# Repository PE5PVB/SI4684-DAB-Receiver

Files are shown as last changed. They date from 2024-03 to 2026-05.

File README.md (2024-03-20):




# Note:
The version in the repository is an ongoing development. It could and will contain bugs. To make sure you use the latest fully tested firmware, check the releases!

# SI4684 DAB receiver
Advanced DAB Tuner software for Skyworks SI4684 tuner with ESP32 board and a color LCD\
More information: https://www.pe5pvb.nl/

# Building instructions
On Youtube I published a video how to build your own radio.

In English:
https://www.youtube.com/watch?v=C_xd0h_HTuU

In Dutch:
https://www.youtube.com/watch?v=wV3G2J327qg

# Libraries
These are the libraries used for this project:
- https://github.com/Bodmer/TFT_eSPI
- https://github.com/Bodmer/JPEGDecoder
- https://github.com/bitbank2/PNGdec

Use these settings in the TFT_eSPI library:
```
#define ILI9341_DRIVER
#define TFT_CS          5
#define TFT_DC          4
#define TFT_RST         17
#define SPI_FREQUENCY   50000000
#define SMOOTH_FONT
```
# Buttons
A brief instruction for the buttons:
- Top encoder: Choose frequency or memory channel
- Bottom encoder: Choose service or set headphones volume
- Top button: Short press: Service information, Long press: Stand-by mode.
- Middle button: Short press: Set mode, Long press: Open menu.
- Lower button: Toggle Slideshow view.
  
## Contributing
I'm open for a new ideas in our project. Feel free to share your thoughts in [Discussions](https://github.com/PE5PVB/SI4684-DAB-Receiver/discussions).\
You can also contribute your own code using [Pull Requests](https://github.com/PE5PVB/SI4684-DAB-Receiver/pulls). We will review it and merge into main branch.

You are using my software and you found a difficulty? Please create new [issue](https://github.com/PE5PVB/SI4684-DAB-Receiver/issues) and describe your problem.

I also would like to invite you to join our Discord community where we share our ideas and help each other with some issues.\
[Join the TEF6686 Discord community!](https://discord.gg/ZAVNdS74mC)  

Special thanks to all [contributors](https://github.com/PE5PVB/TEF-Nextion-Multiband/graphs/contributors). You are awesome! ❤️
## License
This program is free software; you can redistribute it and/or modify it under the terms of the GNU General Public License as published by the Free Software Foundation; either version 3 of the License, or (at your option) any later version.

This program is distributed in the hope that it will be useful, but WITHOUT ANY WARRANTY; without even the implied warranty of MERCHANTABILITY or FITNESS FOR A PARTICULAR PURPOSE. See the GNU General Public License for more details. 

## If you like this software


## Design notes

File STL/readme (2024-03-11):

Many thanks to Eric-Jan de Boer for this 3d case design!

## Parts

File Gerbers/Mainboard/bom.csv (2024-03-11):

Designator | Footprint | Quantity | Value | LCSC Part #
C1, C14, C15, C17, C26, C35, C4, C41 | 0603 | 8 | 1uF
C12, C23, C29, C38 | 0603 | 4 | 8p2
C18, C19, C21, C6 | 0603 | 4 | 100n
C25, C30, C40, C7 | 0603 | 4 | 2n2
C3 | 0603 | 1 | 33p
C34, C39 | 0603 | 2 | 270p
C5 | 0603 | 1 | 2p7
D1 | SOT-23 | 1 | BAV99
L1 | 0603 | 1 | 18nH
L2 | 0603 | 1 | BEAD
L3 | 0603 | 1 | 120nH
L4 | 0603 | 1 | 22nH
R1 | 0603 | 1 | 4k7
R10, R11 | 0603 | 2 | 220
R2, R3, R4, R5, R8, R9 | 0603 | 6 | 100
R25, R26 | 0603 | 2 | 10k
U1 | SOT-23-5 | 1 | MIC5504-1.8YM5
U3 | QFN-48-1EP_7x7mm_P0.5mm_EP5.3x5.3mm | 1 | SI4684-A10-GM
U5 | QFN-20-1EP_4x4mm_P0.5mm_EP2.7x2.7mm | 1 | TPA6130A2RTJTG4 | TPA6130A2RTJTG4
X1 | Crystal_SMD_3225-4Pin_3.2x2.5mm | 1 | 19.2MHz

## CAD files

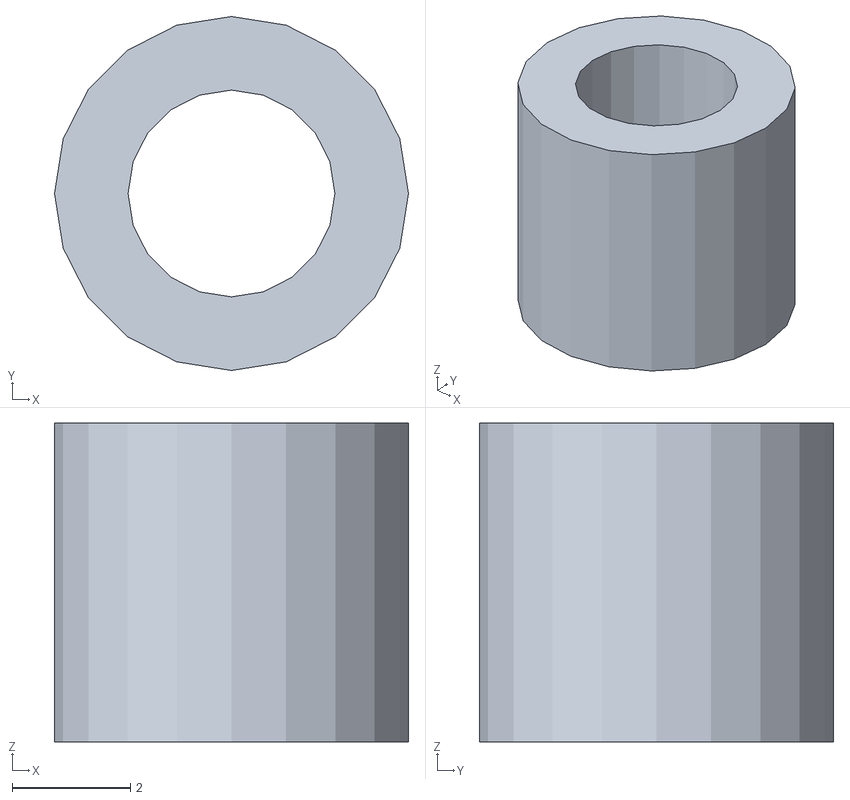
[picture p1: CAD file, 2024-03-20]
STL/bus.stl
6.00 x 6.00 x 5.40

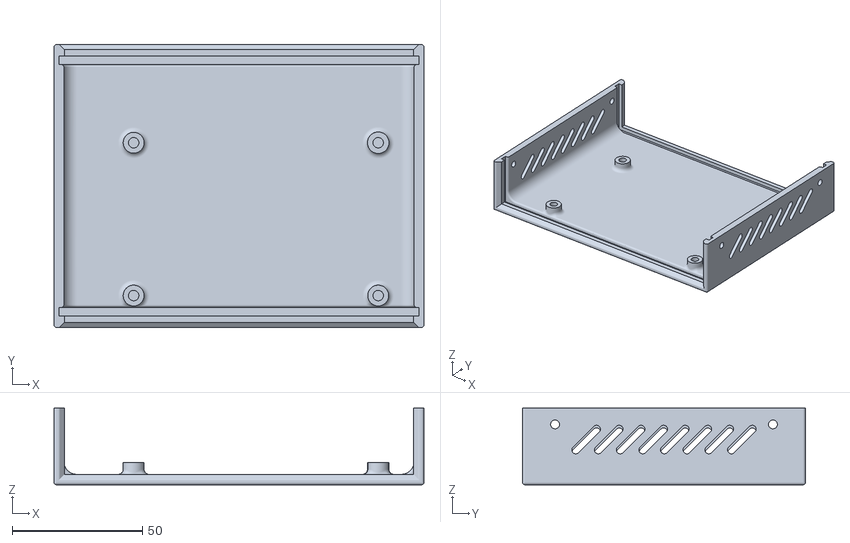
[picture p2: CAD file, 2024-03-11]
STL/bottom.stl
141.9 x 108.5 x 29.4

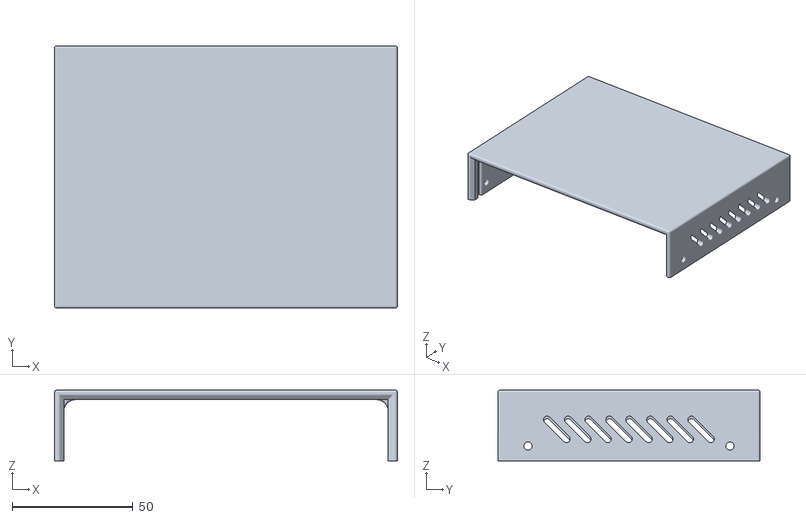
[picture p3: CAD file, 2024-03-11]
STL/top.stl
141.9 x 108.5 x 29.4

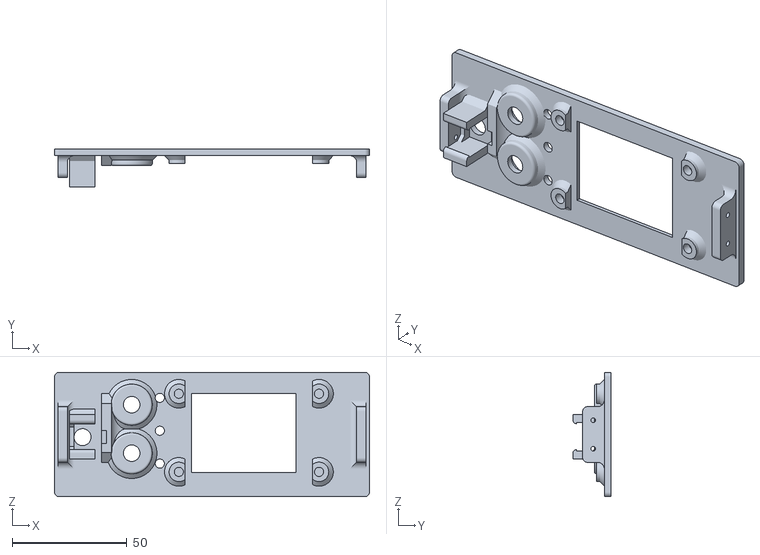
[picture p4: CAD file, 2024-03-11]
STL/front.stl
137.5 x 16.8 x 54.3

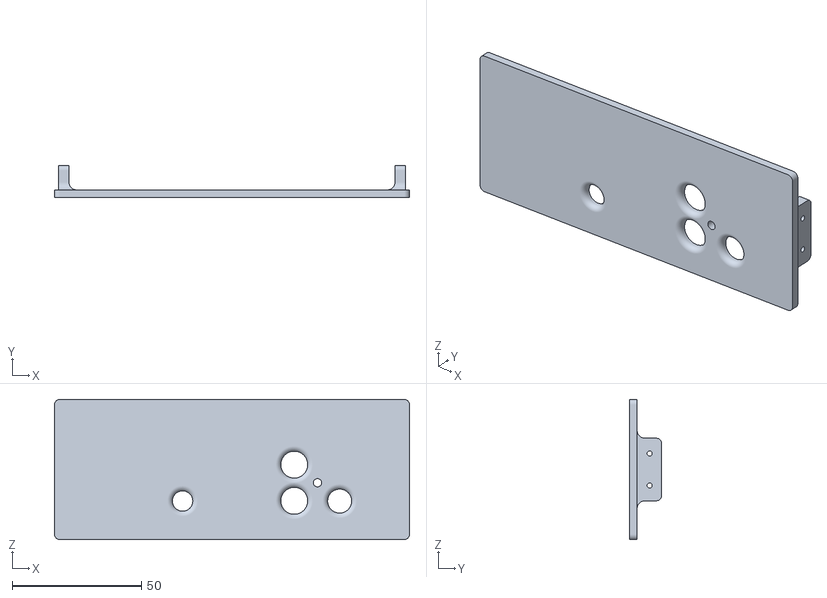
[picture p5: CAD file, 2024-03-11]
STL/back.stl
137.5 x 12.5 x 54.3

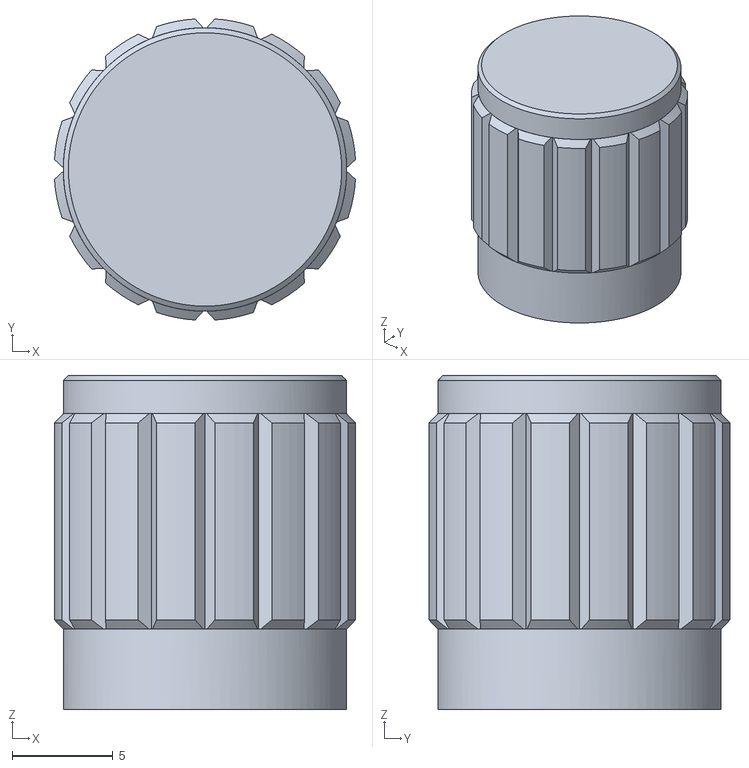
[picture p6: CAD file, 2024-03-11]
STL/rotary knob.stl
15.0 x 15.0 x 16.6

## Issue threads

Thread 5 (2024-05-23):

Petite Modification dand si4684.cpp et .h

GOUNOT, 2024-05-23:
Bonjour ,

Voici les fichier si4684.cpp et . h
Ajout radio.vol(x); Volume de sortie
SID et EID recalculés

Pascal
[si4684h.txt](https://github.com/PE5PVB/SI4684-DAB-Receiver/files/15418648/si4684h.txt)
[si4684cpp.txt](https://github.com/PE5PVB/SI4684-DAB-Receiver/files/15418651/si4684cpp.txt)

PE5PVB, 2024-05-23:
Hi Pascal,

Thanks. I applied your changes to the repository.

Maybe you can help me out with translation of the language.h to French?

BTW. Do you have EPG data on your DAB bouquets? We don’t, and I like to parse now/next EPG for the current service and show it in a separate window when long press the slideshow button.

Sjef

Van: GOUNOT ***@***.***>
Verzonden: donderdag 23 mei 2024 16:57
Aan: PE5PVB/SI4684-DAB-Receiver ***@***.***>
CC: Subscribed ***@***.***>
Onderwerp: [PE5PVB/SI4684-DAB-Receiver] Petite Modification dand si4684.cpp et .h (Issue #5)

Bonjour ,

Voici les fichier si4684.cpp et . h
Ajout radio.vol(x); Volume de sortie
SID et EID recalculés

Pascal
si4684h.txt <https://github.com/PE5PVB/SI4684-DAB-Receiver/files/15418648/si4684h.txt>
si4684cpp.txt <https://github.com/PE5PVB/SI4684-DAB-Receiver/files/15418651/si4684cpp.txt>

—
Reply to this email directly, view it on GitHub <https://github.com/PE5PVB/SI4684-DAB-Receiver/issues/5> , or unsubscribe <https://github.com/notifications/unsubscribe-auth/ASI5LNMQ2QZ265M7S2TS5BLZDX7URAVCNFSM6AAAAABIF2XZHKVHI2DSMVQWIX3LMV43ASLTON2WKOZSGMYTGMJUGUYTKMI> .
You are receiving this because you are subscribed to this thread.  <https://github.com/notifications/beacon/ASI5LNOVHNT73I6TKVCY7Z3ZDX7URA5CNFSM6AAAAABIF2XZHKWGG33NNVSW45C7OR4XAZNFJFZXG5LFVJRW63LNMVXHIX3JMTHITX6LH4.gif> Message ID: ***@***.*** ***@***.***> >

PE5PVB, 2024-06-05:
I tried your modification but it mess up German.
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

Closed 2024-06-05.

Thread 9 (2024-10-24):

Kicad files

alfrede, 2024-10-24:
Hi, thanks for this outstanding Projekt. Will you release the kicad Projekt files?

PE5PVB, 2025-01-22:
Why do you want the source files?

nona00, 2025-01-26:
Great project! With the KiCad files, one could design simplified PCBs, for example, a breakout board for ESP32. Smaller than DAB Shield.

PE5PVB, 2025-01-26:
Just added the Kicad files. Please respect the license.

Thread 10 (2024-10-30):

Utilisation VScode et PlatformIO and  Partition of ESP32 memory

joellecam, 2024-10-30:
Hi,

First, You have made a very good project. I am retired from an Electronics job of 42 years.  For my hobby I continue some projects. for software I prefer VScode with platformio vs Arduino Ide.   I have made my dabshield pcb (photo) and I try to adapt your software.

I try to use VScode with PlatformIO to works and run the SI4684-DAB. the compilation generate a too big exe file. I change the partition files to have no OTA, that double the application place.  see partition file --> File ESP32_4MB_NON_OTA.csv hereunder.
Then the compilation is done without error and I have free space memory.  the dowloading  was aso ok.

when rebboting  I have an error at the begining when fuction  "LittleFS.begin()" run. see hereunder. Is the error due to the partition scheme?

Platformio.ini  ( with LittleFS  build filesystem and partitions scheme)
```
; https://docs.platformio.org/page/projectconf.html
[env:esp32dev]
platform = espressif32
board = esp32dev
monitor_speed = 115200
board_build.partitions = ESP32_4MB_NON_OTA.csv
board_build.filesystem = littlefs
framework = arduino
```

File ESP32_4MB_NON_OTA.csv
```
# Name,   Type, SubType, Offset,  Size, Flags
nvs,      data, nvs,     0x9000,  0x5000,
otadata,  data, ota,     0xe000,  0x2000,
app0,     app,  ota_0,   0x10000, 0x280000,
spiffs,   data, spiffs,  0x290000,0x150000,
coredump, data, coredump,0x3F0000,0x10000,
```

debug monitor listing

```
--------------------
Rebooting...
LittleFS.begin()

assert failed: lfs_fs_grow_ lfs.c:5165 (block_count >= lfs->block_count)

Backtrace: 0x40083cc5:0x3ffb1e50 0x4008bd81:0x3ffb1e70 0x400916dd:0x3ffb1e90 0x4010546c:0x3ffb1fc0 0x40100f76:0x3ffb2020 0x40101082:0x3ffb2070 0x400de4fd:0x3ffb21e0 0x400dab56:0x3ffb2210 0x400ee1ca:0x3ffb2290

ELF file SHA256: 87c1a721b5c09ac3
Rebooting...
-------------------
```
Thanks very much for your help.

Joël  , leeve in Normandie, France.
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

Closed 2024-10-30.

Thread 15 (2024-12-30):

to much memory

McKaiver, 2024-12-30:
when i compile the scetch with all libraries, i get the warning:
Sketch is using 3180057 Bytes (242%)

i have this controller:
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

what's wrong here?

PE5PVB, 2024-12-30:
Select "High APP" for compiling and use ESP32 boardmanager v2.x

McKaiver, 2024-12-30:
I'm using Arduino IDE 2.2.1

Closed 2025-02-24.

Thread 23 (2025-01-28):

Reduced Circuit for I2S Output

harryberlin, 2025-01-28:
Hello,

inspired by your project i designed a PCB for ESP32 with PCM5102 and SI468**8**, instead of SI468**4**

[AVR-IBus.dab.schematic.pdf](https://github.com/user-attachments/files/18578988/AVR-IBus.dab.schematic.pdf)

<Image width=300 src=https://github.com/user-attachments/assets/85ba1679-1bd4-4248-8c1a-f421ad6ef8ed>

(BTW. Reset and Boot Mode has an error)

For first Test i have stripped and added some prints to your code.
After begin the IC returns "SI0" ChipID and "0.0.0" as Firmware Version
that's the result of setup method:

```
void setup(void) {
  WRITE_PERI_REG(RTC_CNTL_BROWN_OUT_REG, 0);

  setupmode = true;

  Serial.begin(115200);
  Serial.println("SETUP STARTING ....");
  pinMode(RESET_PIN, OUTPUT);
  digitalWrite(RESET_PIN, LOW);
  delay(50);
  digitalWrite(RESET_PIN, HIGH);
  delay(50);

  EEPROM.begin(EE_TOTAL_CNT);
  if (EEPROM.readByte(EE_BYTE_CHECKBYTE) != EE_CHECKBYTE_VALUE) DefaultSettings();
  ContrastSet = EEPROM.readByte(EE_BYTE_CONTRASTSET);
  language = EEPROM.readByte(EE_BYTE_LANGUAGE);
  displayflip = EEPROM.readByte(EE_BYTE_DISPLAYFLIP);
  rotarymode = EEPROM.readByte(EE_BYTE_ROTARYMODE);
  tunemode = EEPROM.readByte(EE_BYTE_TUNEMODE);
  unit = EEPROM.readByte(EE_BYTE_UNIT);
  dabfreq = EEPROM.readByte(EE_BYTE_DABFREQ);
  volume = EEPROM.readByte(EE_BYTE_VOLUME);
  memorypos = EEPROM.readByte(EE_BYTE_MEMORYPOS);
  autoslideshow = EEPROM.readByte(EE_BYTE_AUTOSLIDESHOW);
  tot = EEPROM.readByte(EE_BYTE_TOT);
  CurrentTheme = EEPROM.readByte(EE_BYTE_THEME);
  //radio.BufferSlideShow = EEPROM.readByte(EE_BYTE_BUFFERSLIDESHOW);

  for (int i = 0; i < EE_PRESETS_CNT; i++) {
    memory[i].Channel = EEPROM.readByte(i + EE_PRESETS_FREQ_START);
    EEPROM.get((i * 8) + EE_PRESETS_SERVICEID_START, memory[i].ServiceID);
    for (int y = 0; y < 16; y++) {
      memory[i].Label[y] = EEPROM.readByte((i * 17) + y + EE_PRESETS_NAME_START);
    }
    memory[i].Label[16] = '\0';
  }
  Serial.println("EEPROM DONE");

  delay(50);

  Serial.println("Starting DAB.....");
  if (radio.begin(15)) {
    Serial.println("Starting DAB OK");
  } else {
    for (;;);
  }

  delay(1500);
  Serial.println("Starting DAB DONE");
  Serial.println("TUNE ...");
  if (tunemode == TUNE_MEM && !IsStationEmpty()) {
    DoMemoryPosTune();
  } else {
    if (tunemode == TUNE_MEM) tunemode = TUNE_MAN;
    radio.setFreq(dabfreq);
    EEPROM.get(EE_UINT32_SERVICEID, _serviceID);
    for (int i = 0; i < 16; i++) {
      _serviceName[i] = EEPROM.readByte(i + EE_CHAR17_SERVICENAME);
    }
  }
  if (_serviceID != 0 ) trysetservice = true;

  Serial.println("TUNE DONE");
  setupmode = false;
  tottimer = millis();

  Serial.println("SETUP DONE");
  Serial.println(String(radio.getChipID()));
  Serial.println(String(radio.getFirmwareVersion()));
}
```

that's my log
```
19:48:30.479> ets Jul 29 2019 12:21:46
19:48:30.479>
19:48:30.479> rst:0x1 (POWERON_RESET),boot:0x13 (SPI_FAST_FLASH_BOOT)
19:48:30.479> configsip: 0, SPIWP:0xee
19:48:30.479> clk_drv:0x00,q_drv:0x00,d_drv:0x00,cs0_drv:0x00,hd_drv:0x00,wp_drv:0x00
19:48:30.479> mode:DIO, clock div:1
19:48:30.479> load:0x3fff0030,len:1344
19:48:30.479> load:0x40078000,len:13964
19:48:30.479> load:0x40080400,len:3600
19:48:30.479> entry 0x400805f0
19:48:30.779> SETUP STARTING ....
19:48:30.917> EEPROM DONE
19:48:30.979> Starting DAB.....
19:48:30.979> SPIbuffer[1]:0x80
19:48:31.032> DAB WRITE FIRMWARE
19:48:32.532> DAB WRITE FREQLIST
19:48:32.601> Starting DAB OK
19:48:34.101> Starting DAB DONE
19:48:54.144> SETUP DONE
19:48:54.144> SI0
19:48:54.144> 0.0.0
```

Are there some possible tests to find the problem?
Do you think your firmware is not for the IC?
I hope you could give some support, to get my device working?

PE5PVB, 2025-01-31:
Hi,

Are you sure the RST pin on the chip is at 3V3 when set to high?

Sjef

harryberlin schreef op 2025-01-28 21:45:
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

harryberlin, 2025-01-31:
The Multimeter shows 3,287V at ESP32 IO17.

at the moment i have a very simple sketch:
now i will try to get forward step by step, by adding the other commands.
```
#include <SPI.h>
#include "firmware.h"
#include "Si468xROM.h"

unsigned char SPIbuffer[4096];
uint8_t slaveSelectPin = 15;
uint8_t RESET_PIN = 17;

void setup() {
  Serial.begin(115200);
  Serial.println("SETUP STARTING ....");

  pinMode(RESET_PIN, OUTPUT);
  digitalWrite(RESET_PIN, LOW);
  delay(50);
  digitalWrite(RESET_PIN, HIGH);

  pinMode(slaveSelectPin, OUTPUT);                                        // Configure SPI
  digitalWrite(slaveSelectPin, HIGH);
  SPI.begin(14, 16, 13, slaveSelectPin);
  delay(3);

  SPIbuffer[0] = 0x09;
  SPIbuffer[1] = 0x00;
  SPIwrite(SPIbuffer, 2);
  cts();
  SPIread(10);

  for (int i = 0; i < 10; i++) {
    Serial.printf("SPIbuffer[%d]:", i);
    Serial.println(SPIbuffer[i], HEX);
  }

  if (SPIbuffer[1] != 2) {

    SPIbuffer[0] = 0x01;                                                    // POWER_UP
    SPIbuffer[1] = 0x00;
    SPIbuffer[2] = 0x17;
    SPIbuffer[3] = 0x48;
    SPIbuffer[4] = 0x00;
    SPIbuffer[5] = 0xf8;
    SPIbuffer[6] = 0x24;
    SPIbuffer[7] = 0x01;
    SPIbuffer[8] = 0x1F;
    SPIbuffer[9] = 0x10;
    SPIbuffer[10] = 0x00;
    SPIbuffer[11] = 0x00;
    SPIbuffer[12] = 0x00;
    SPIbuffer[13] = 0x18;
    SPIbuffer[14] = 0x00;
    SPIbuffer[15] = 0x00;

    SPIwrite(SPIbuffer, 16);
    cts();

    delayMicroseconds(20);

    SPIbuffer[0] = 0x06;                                                    // LOAD_INIT
    SPIbuffer[1] = 0x00;
    SPIwrite(SPIbuffer, 2);
    cts();

    Serial.println("WRITE BOOTLOADER");
    uint32_t index = 0;                                                     // Write bootloader
    for (uint16_t i = 0; index < sizeof(rom_patch_016); i++) {
      SPIbuffer[0] = 0x04;
      SPIbuffer[1] = 0x00;
      SPIbuffer[2] = 0x00;
      SPIbuffer[3] = 0x00;
      for (uint16_t j = 4; j < 128 && index < sizeof(rom_patch_016); j++, index++) SPIbuffer[j] = pgm_read_byte_near(rom_patch_016 + index);
      SPIwrite(SPIbuffer, 128);
      cts();
    }

    delay(4);
    SPIbuffer[0] = 0x06;                                                    // LOAD_INIT
    SPIbuffer[1] = 0x00;
    SPIwrite(SPIbuffer, 2);
    cts();

  }

  delay(4);
  SPIbuffer[0] = 0x09;
  SPIbuffer[1] = 0x00;
  SPIwrite(SPIbuffer, 2);
  cts();
  SPIread(10);

  for (int i = 0; i < 10; i++) {
    Serial.printf("SPIbuffer[%d]:", i);
    Serial.println(SPIbuffer[i], HEX);
  }

  delay(4);
  SPIbuffer[0] = 0x12;
  SPIbuffer[1] = 0x00;
  SPIwrite(SPIbuffer, 2);
  cts();
  SPIread(10);

  for (int i = 0; i < 10; i++) {
    Serial.printf("SPIbuffer[%d]:", i);
    Serial.println(SPIbuffer[i], HEX);
  }

  delay(4);
  char ChipType[7];
  SPIbuffer[0] = 0x08;
  SPIbuffer[1] = 0x00;
  SPIwrite(SPIbuffer, 2);
  cts();
  SPIread(23);
  itoa((SPIbuffer[10] << 8) + SPIbuffer[9], ChipType + 2, 10);
  ChipType[0] = 'S';
  ChipType[1] = 'I';
  ChipType[6] = '\0';
  Serial.println(ChipType);

}

void loop() {
  // put your main code here, to run repeatedly:

}

static void SPIwrite(unsigned char *data, uint32_t length) {
  SPI.beginTransaction(SPISettings(10000000, MSBFIRST, SPI_MODE0));
  digitalWrite (slaveSelectPin, LOW);
  SPI.transfer(data, length);
  digitalWrite (slaveSelectPin, HIGH);
  SPI.endTransaction();
}

static void SPIread(uint16_t length) {
  for (uint16_t i = 0; i < length + 1; i++) SPIbuffer[i] = 0;
  SPIwrite(SPIbuffer, length + 1);
}

static void cts(void) {
  bool timeout = false;
  uint16_t countdown = 1000;
  while (!(SPIbuffer[1] & 0x80)) {
    delay(4);
    for (byte i = 0; i < 5; i++) SPIbuffer[i] = 0;
    SPIwrite(SPIbuffer, 5);
    countdown--;
    if (countdown == 0) {
      timeout = true;
      break;
    }
  }

  if (SPIbuffer[1] & 0x40) {
    for (byte i = 0; i < 5; i++) SPIbuffer[i] = 0;
    if (timeout) SPIbuffer[5] |= (1 << 7);
  }
}
```

log:
```
21:59:47.236> ets Jul 29 2019 12:21:46
21:59:47.236>
21:59:47.236> rst:0x1 (POWERON_RESET),boot:0x13 (SPI_FAST_FLASH_BOOT)
21:59:47.236> configsip: 0, SPIWP:0xee
21:59:47.236> clk_drv:0x00,q_drv:0x00,d_drv:0x00,cs0_drv:0x00,hd_drv:0x00,wp_drv:0x00
21:59:47.236> mode:DIO, clock div:
21:59:47.236> load:0x3fff0030,len:4916
21:59:47.236> load:0x40078000,len:16436
21:59:47.236> load:0x40080400,len:4
21:59:47.236> ho 8 tail 4 room 4
21:59:47.236> load:0x40080404,len:3524
21:59:47.236> entry 0x400805b8
21:59:47.299> E (134) esp_core_`fW
}™±…Í¡é Incorrect size of core dump image: 1568905280
21:59:47.361> SETUP STARTING ....
21:59:47.424> SPIbuffer[0]:0
21:59:47.424> SPIbuffer[1]:80
21:59:47.424> SPIbuffer[2]:0
21:59:47.424> SPIbuffer[3]:0
21:59:47.424> SPIbuffer[4]:0
21:59:47.424> SPIbuffer[5]:0
21:59:47.424> SPIbuffer[6]:0
21:59:47.424> SPIbuffer[7]:0
21:59:47.424> SPIbuffer[8]:0
21:59:47.424> SPIbuffer[9]:0
21:59:47.424> WRITE BOOTLOADER
21:59:47.611> SPIbuffer[0]:0
21:59:47.611> SPIbuffer[1]:80
21:59:47.611> SPIbuffer[2]:0
21:59:47.611> SPIbuffer[3]:0
21:59:47.611> SPIbuffer[4]:0
21:59:47.611> SPIbuffer[5]:0
21:59:47.611> SPIbuffer[6]:0
21:59:47.611> SPIbuffer[7]:0
21:59:47.611> SPIbuffer[8]:0
21:59:47.611> SPIbuffer[9]:0
21:59:47.674> SPIbuffer[0]:0
21:59:47.674> SPIbuffer[1]:80
21:59:47.674> SPIbuffer[2]:0
21:59:47.674> SPIbuffer[3]:0
21:59:47.674> SPIbuffer[4]:0
21:59:47.674> SPIbuffer[5]:0
21:59:47.674> SPIbuffer[6]:0
21:59:47.674> SPIbuffer[7]:0
21:59:47.674> SPIbuffer[8]:0
21:59:47.674> SPIbuffer[9]:0
21:59:47.674> SI0
```

harryberlin, 2025-01-31:
next result:
```
#include <SPI.h>
#include "firmware.h"
#include "Si468xROM.h"

struct DABFrequencyLabel_DAB {
  uint32_t frequency;
  const char* label;
};

const DABFrequencyLabel_DAB DABfrequencyTable_DAB[] = {
  { 174928,  "5A"}, { 176640,  "5B"}, { 178352,  "5C"}, { 180064,  "5D"},
  { 181936,  "6A"}, { 183648,  "6B"}, { 185360,  "6C"}, { 187072,  "6D"},
  { 188928,  "7A"}, { 190640,  "7B"}, { 192352,  "7C"}, { 194064,  "7D"},
  { 195936,  "8A"}, { 197648,  "8B"}, { 199360,  "8C"}, { 201072,  "8D"},
  { 202928,  "9A"}, { 204640,  "9B"}, { 206352,  "9C"}, { 208064,  "9D"},
  { 209936, "10A"}, { 211648, "10B"}, { 213360, "10C"}, { 215072, "10D"},
  { 216928, "11A"}, { 218640, "11B"}, { 220352, "11C"}, { 222064, "11D"},
  { 223936, "12A"}, { 225648, "12B"}, { 227360, "12C"}, { 229072, "12D"},
  { 230784, "13A"}, { 232496, "13B"}, { 234208, "13C"}, { 235776, "13D"},
  { 237488, "13E"}, { 239200, "13F"}
};

unsigned char SPIbuffer[4096];
uint8_t slaveSelectPin = 15;
uint8_t RESET_PIN = 17;

void setup() {
  Serial.begin(115200);
  Serial.println("SETUP STARTING ....");

  pinMode(RESET_PIN, OUTPUT);
  digitalWrite(RESET_PIN, LOW);
  //delay(50);
  digitalWrite(RESET_PIN, HIGH);

  /* leds on
    pinMode(2, OUTPUT);
    digitalWrite(2, HIGH);
    pinMode(4, OUTPUT);
    digitalWrite(4, HIGH);
    pinMode(5, OUTPUT);
    digitalWrite(5, HIGH);*/

  Serial.println("Configure SPI");
  pinMode(slaveSelectPin, OUTPUT);                                        // Configure SPI
  digitalWrite(slaveSelectPin, HIGH);
  SPI.begin(14, 16, 13, slaveSelectPin);
  delay(3);
  SPIbuffer[0] = 0x09;
  SPIbuffer[1] = 0x00;
  SPIwrite(SPIbuffer, 2);
  cts();
  SPIread(6);

  bool result;
  if (SPIbuffer[1] != 0x80) {
    result = false;
  } else {
    result = true;
  }

  if (SPIbuffer[1] != 2) {
    //Serial.println("POWER_UP");

    SPIbuffer[0] = 0x01;                                                    // POWER_UP
    SPIbuffer[1] = 0x00;
    SPIbuffer[2] = 0x17;
    SPIbuffer[3] = 0x48;
    SPIbuffer[4] = 0x00;
    SPIbuffer[5] = 0xf8;
    SPIbuffer[6] = 0x24;
    SPIbuffer[7] = 0x01;
    SPIbuffer[8] = 0x1F;
    SPIbuffer[9] = 0x10;
    SPIbuffer[10] = 0x00;
    SPIbuffer[11] = 0x00;
    SPIbuffer[12] = 0x00;
    SPIbuffer[13] = 0x18;
    SPIbuffer[14] = 0x00;
    SPIbuffer[15] = 0x00;
    SPIwrite(SPIbuffer, 16);
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

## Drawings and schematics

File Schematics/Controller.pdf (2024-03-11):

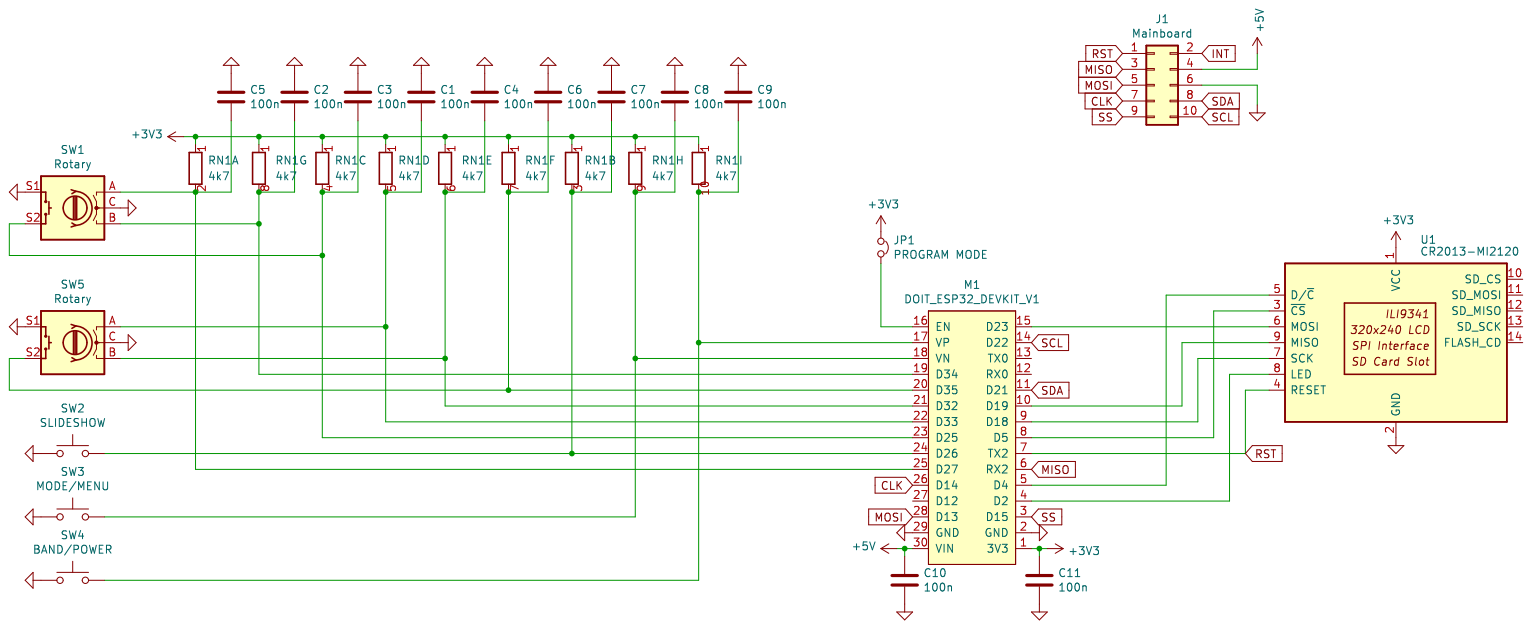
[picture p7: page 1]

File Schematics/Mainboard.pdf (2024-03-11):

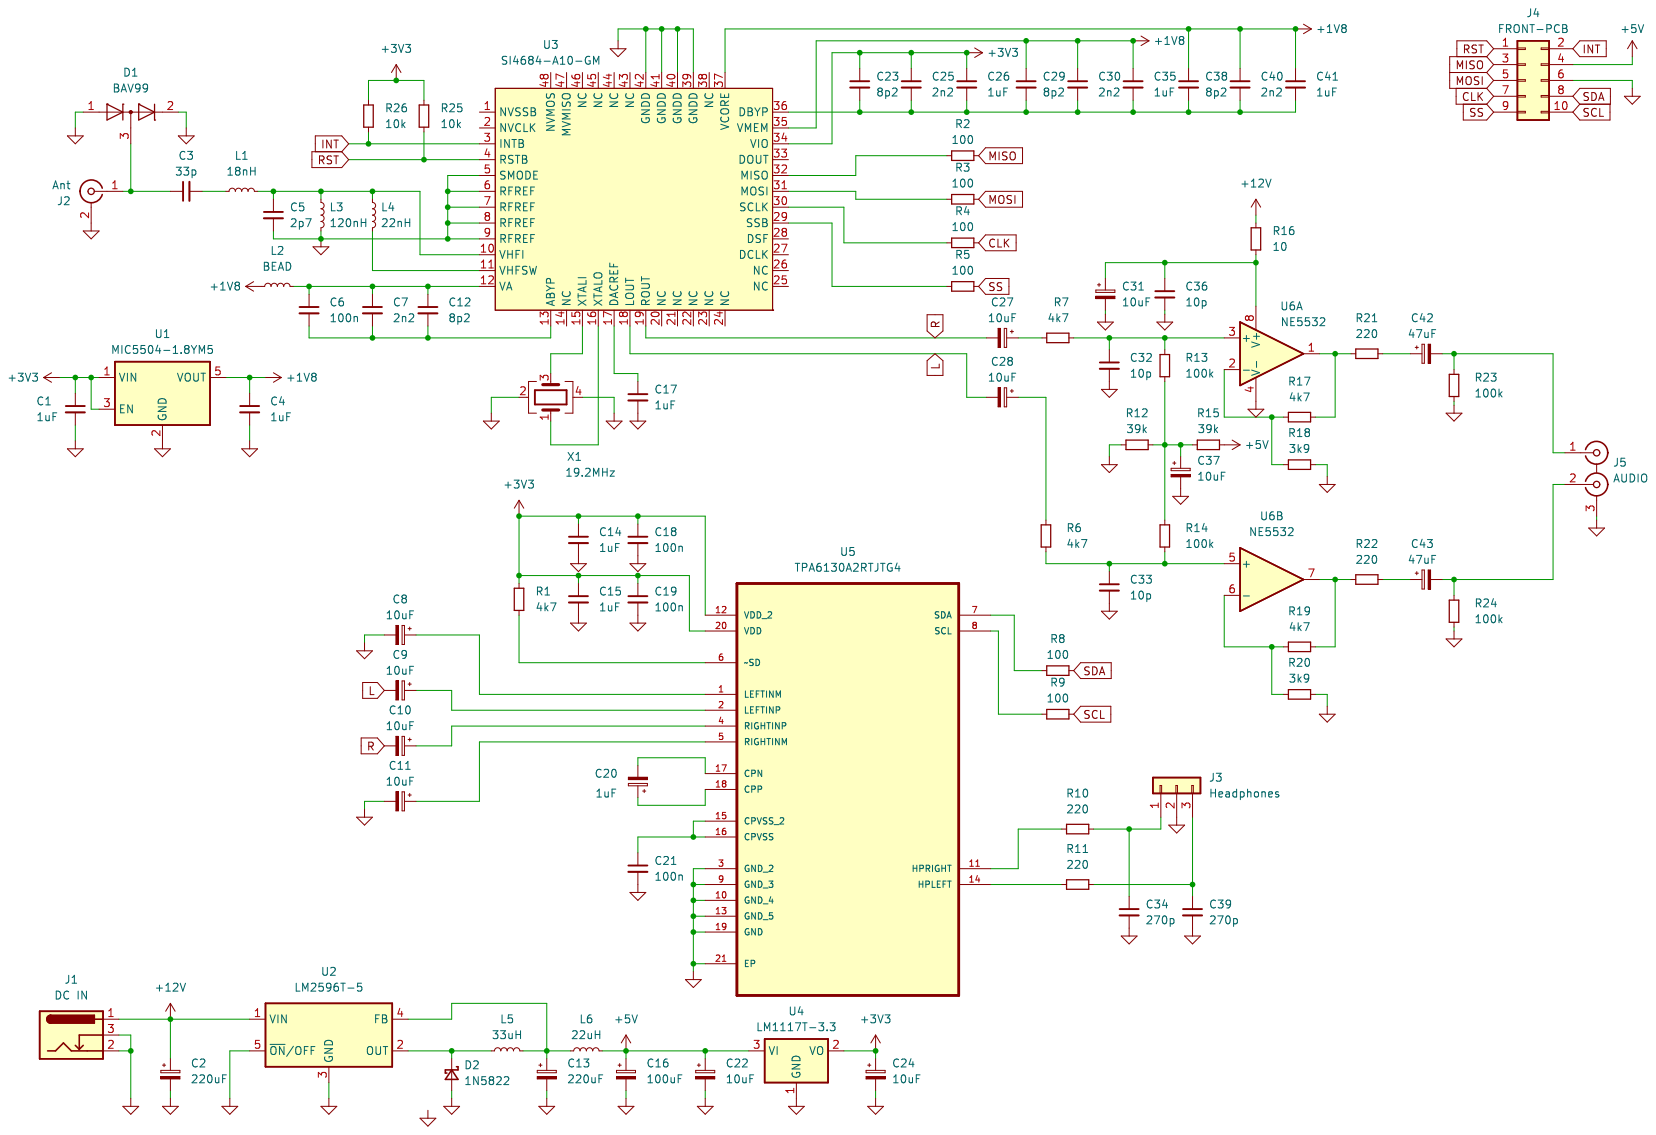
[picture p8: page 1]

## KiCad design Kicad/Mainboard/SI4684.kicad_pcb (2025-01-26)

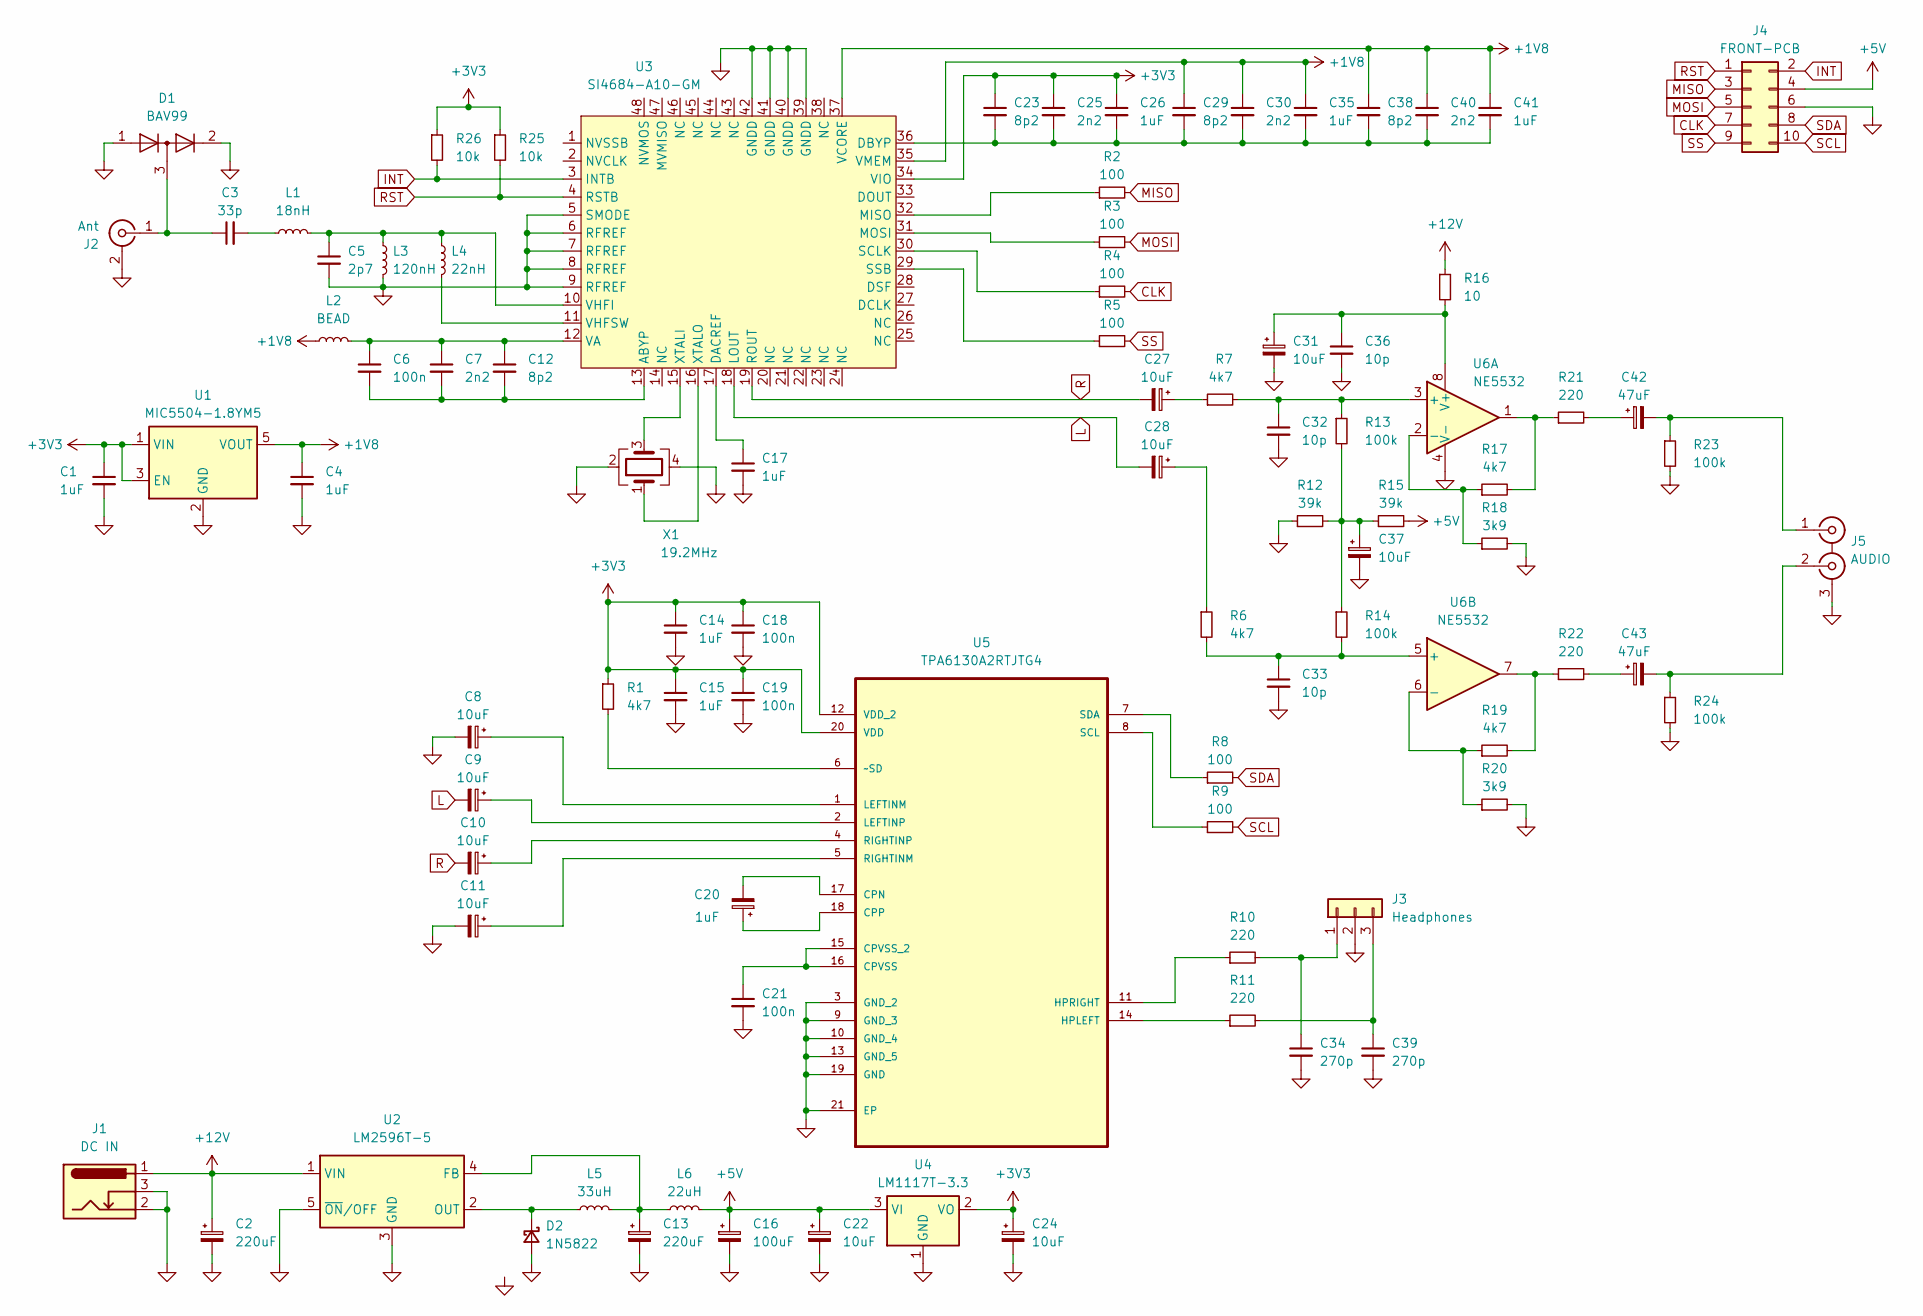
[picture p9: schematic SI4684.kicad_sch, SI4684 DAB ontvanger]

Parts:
C1, C4, C14, C15, C17, C26, C35, C41: 1uF; C_0603_1608Metric
C2, C13: 220uF; CP_Radial_D10.0mm_P3.50mm
C3: 33p; C_0603_1608Metric
C5: 2p7; C_0603_1608Metric
C6, C18, C19, C21: 100n; C_0603_1608Metric
C7, C25, C30, C40: 2n2; C_0603_1608Metric
C8, C9, C10, C11, C22, C24, C27, C28, C31, C37: 10uF; CP_Radial_D5.0mm_P2.00mm
C12, C23, C29, C38: 8p2; C_0603_1608Metric
C16: 100uF; CP_Radial_D10.0mm_P3.50mm
C20: 1uF; CP_Radial_D5.0mm_P2.00mm
C32, C33, C36: 10p; C_Disc_D3.0mm_W2.0mm_P2.50mm
C34, C39: 270p; C_0603_1608Metric
C42, C43: 47uF; CP_Radial_D5.0mm_P2.00mm
D1: BAV99; SOT-23
D2: 1N5822; D_DO-201_P12.70mm_Horizontal
J1: DC IN; BarrelJack_Horizontal
J2: Ant; SMA_Amphenol_132134-16_Vertical
J3: Headphones; JST_PH_B3B-PH-K_1x03_P2.00mm_Vertical
J4: FRONT-PCB; IDC-Header_2x05_P2.54mm_Vertical
J5: AUDIO; FC68405_cinch
L1: 18nH; L_0603_1608Metric
L2: BEAD; L_0603_1608Metric
L3: 120nH; L_0603_1608Metric
L4: 22nH; L_0603_1608Metric
L5: 33uH; L_Radial_D7.2mm_P3.00mm_Murata_1700
L6: 22uH; L_Radial_D7.2mm_P3.00mm_Murata_1700
R1: 4k7; R_0603_1608Metric
R2, R3, R4, R5, R8, R9: 100; R_0603_1608Metric
R6, R7, R17, R19: 4k7; R_Axial_DIN0207_L6.3mm_D2.5mm_P10.16mm_Horizontal
R10, R11: 220; R_0603_1608Metric
R12, R15: 39k; R_Axial_DIN0207_L6.3mm_D2.5mm_P10.16mm_Horizontal
R13, R14, R23, R24: 100k; R_Axial_DIN0207_L6.3mm_D2.5mm_P10.16mm_Horizontal
R16: 10; R_Axial_DIN0207_L6.3mm_D2.5mm_P10.16mm_Horizontal
R18, R20: 3k9; R_Axial_DIN0207_L6.3mm_D2.5mm_P10.16mm_Horizontal
R21, R22: 220; R_Axial_DIN0207_L6.3mm_D2.5mm_P10.16mm_Horizontal
R25, R26: 10k; R_0603_1608Metric
U1: MIC5504-1.8YM5; SOT-23-5
U2: LM2596T-5; TO-220-5_Vertical
U3: SI4684-A10-GM; QFN-48-1EP_7x7mm_P0.5mm_EP5.3x5.3mm
U4: LM1117T-3.3; TO-220-3_Vertical
U5: TPA6130A2RTJTG4; QFN-20-1EP_4x4mm_P0.5mm_EP2.7x2.7mm; MPN TPA6130A2RTJTG4
U6: NE5532; DIP-8_W7.62mm_LongPads
X1: 19.2MHz; Crystal_SMD_3225-4Pin_3.2x2.5mm

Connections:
+1V8: C4.1, C29.1, C30.1, C35.1, C38.1, C40.1, C41.1, L2.1, U1.5 (VOUT), U3.35 (VMEM), U3.37 (VCORE)
+3V3: C1.1, C14.1, C15.1, C18.1, C19.1, C23.1, C24.1, C25.1, C26.1, R1.1, R25.1, R26.1, U1.1 (VIN), U1.3 (EN), U3.34 (VIO), U4.2 (VO), U5.12 (VDD_2), U5.20 (VDD)
+5V: C16.1, C22.1, J4.4, L6.2, R15.2, U4.3 (VI)
+12V: C2.1, J1.1, R16.1, U2.1 (VIN)
CLK: J4.7, R4.2
GND: C1.2, C2.2, C4.2, C5.2, C8.2, C11.2, C13.2, C14.2, C15.2, C16.2, C17.2, C18.2, C19.2, C21.2, C22.2, C24.2, C31.2, C32.2, C33.2, C34.2, C36.2, C37.2, C39.2, D1.1 (K), D1.2 (A), D2.2 (A), J1.2, J1.3, J2.2 (Ext), J3.2, J4.6, J5.3 (EXT), L3.2, R12.1, R18.2, R20.2, R23.2, R24.2, U1.2 (GND), U2.3 (GND), U2.5 (~ON/OFF), U3.5 (SMODE), U3.6 (RFREF), U3.7 (RFREF), U3.8 (RFREF), U3.9 (RFREF), U3.39 (GNDD), U3.40 (GNDD), U3.41 (GNDD), U3.42 (GNDD), U3.49 (GND), U4.1 (GND), U5.3 (GND_2), U5.9 (GND_3), U5.10 (GND_4), U5.13 (GND_5), U5.19 (GND), U5.21 (EP), U6.4 (V-), X1.2, X1.4
INT: J4.2, R26.2, U3.3 (INTB)
L: C9.2, C28.2, U3.18 (LOUT)
MISO: J4.3, R2.2
MOSI: J4.5, R3.2
unnamed: C3.2, L1.1
unnamed: C27.1, R7.1
unnamed: C28.1, R6.1
unnamed: C37.1, R12.2, R13.2, R14.1, R15.1
unnamed: C42.1, R21.2
unnamed: C43.1, R22.2
unnamed: D2.1 (K), L5.1, U2.2 (OUT)
unnamed: C3.1, D1.3 (K), J2.1 (In)
unnamed: C34.1, J3.1, R10.2
unnamed: C39.1, J3.3, R11.2
unnamed: C42.2, J5.1 (IN1), R23.1
unnamed: C43.2, J5.2 (IN2), R24.1
unnamed: R17.2, R21.1, U6.1
unnamed: R19.2, R22.1, U6.7
unnamed: C13.1, L5.2, L6.1, U2.4 (FB)
unnamed: C6.2, C7.2, C12.2, U3.13 (ABYP)
unnamed: C17.1, U3.17 (DACREF)
unnamed: C23.2, C25.2, C26.2, C29.2, C30.2, C35.2, C38.2, C40.2, C41.2, U3.36 (DBYP)
unnamed: R2.1, U3.32 (MISO)
unnamed: R3.1, U3.31 (MOSI)
unnamed: R4.1, U3.30 (SCLK)
unnamed: R5.1, U3.29 (SSB)
unnamed: C6.1, C7.1, C12.1, L2.2, U3.12 (VA)
unnamed: C5.1, L1.2, L3.1, L4.1, U3.10 (VHFI)
unnamed: L4.2, U3.11 (VHFSW)
unnamed: U3.15 (XTALI), X1.3
unnamed: U3.16 (XTALO), X1.1
unnamed: C20.2, U5.17 (CPN)
unnamed: C20.1, U5.18 (CPP)
unnamed: C21.1, U5.15 (CPVSS_2), U5.16 (CPVSS)
unnamed: R11.1, U5.14 (HPLEFT)
unnamed: R10.1, U5.11 (HPRIGHT)
unnamed: C8.1, U5.1 (LEFTINM)
unnamed: C9.1, U5.2 (LEFTINP)
unnamed: C11.1, U5.5 (RIGHTINM)
unnamed: C10.1, U5.4 (RIGHTINP)
unnamed: R9.1, U5.8 (SCL)
unnamed: R8.1, U5.7 (SDA)
unnamed: R1.2, U5.6 (~SD)
unnamed: C32.1, R7.2, R13.1, U6.3 (+)
unnamed: R17.1, R18.1, U6.2 (-)
unnamed: C33.1, R6.2, R14.2, U6.5 (+)
unnamed: R19.1, R20.1, U6.6 (-)
unnamed: C31.1, C36.1, R16.2, U6.8 (V+)
R: C10.2, C27.2, U3.19 (ROUT)
RST: J4.1, R25.2, U3.4 (RSTB)
SCL: J4.10, R9.2
SDA: J4.8, R8.2
SS: J4.9, R5.2

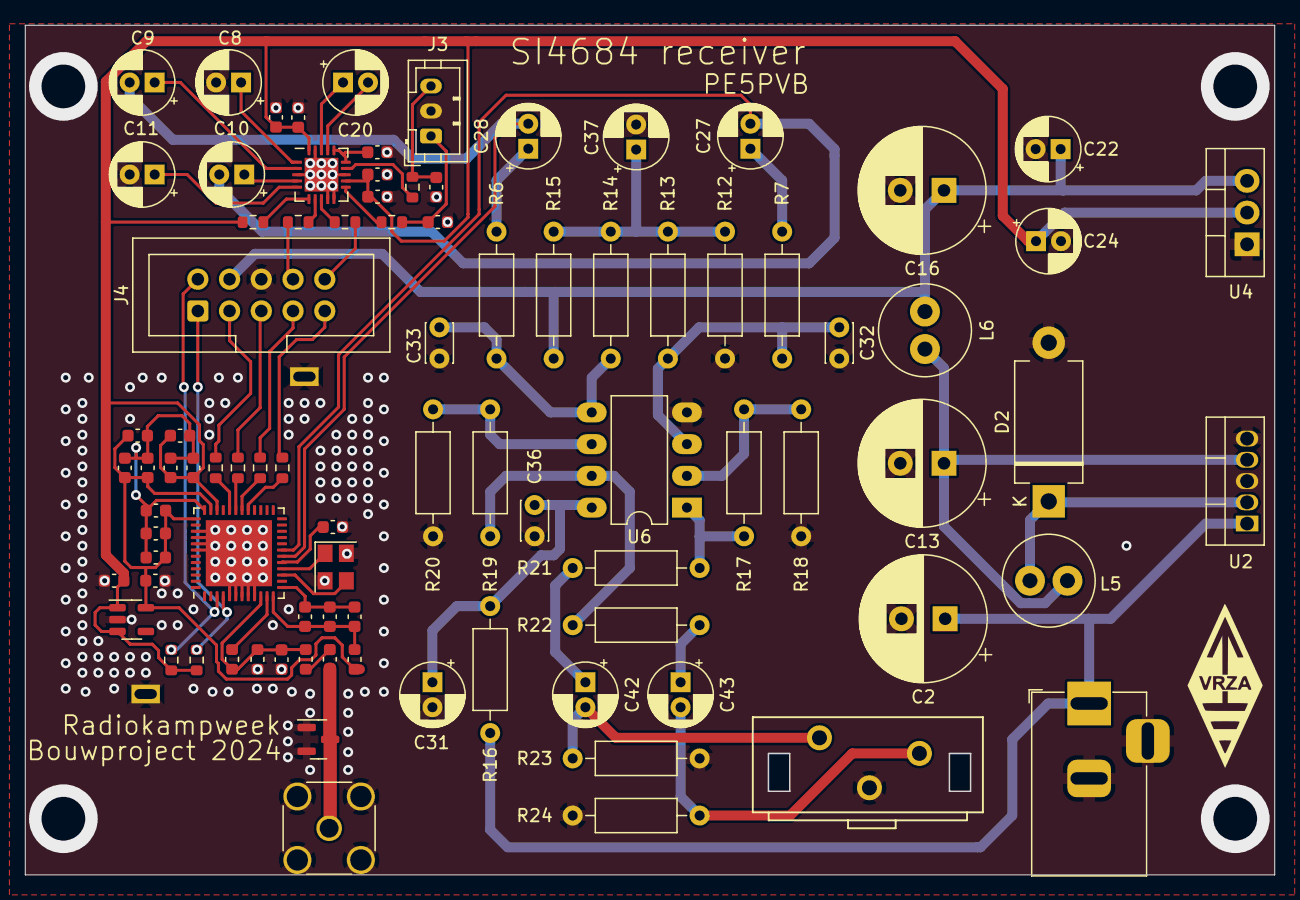
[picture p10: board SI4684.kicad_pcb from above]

Board: 2 copper layers, 100.0 x 68.0 mm, 89 parts (0 on the bottom side), 59 nets.

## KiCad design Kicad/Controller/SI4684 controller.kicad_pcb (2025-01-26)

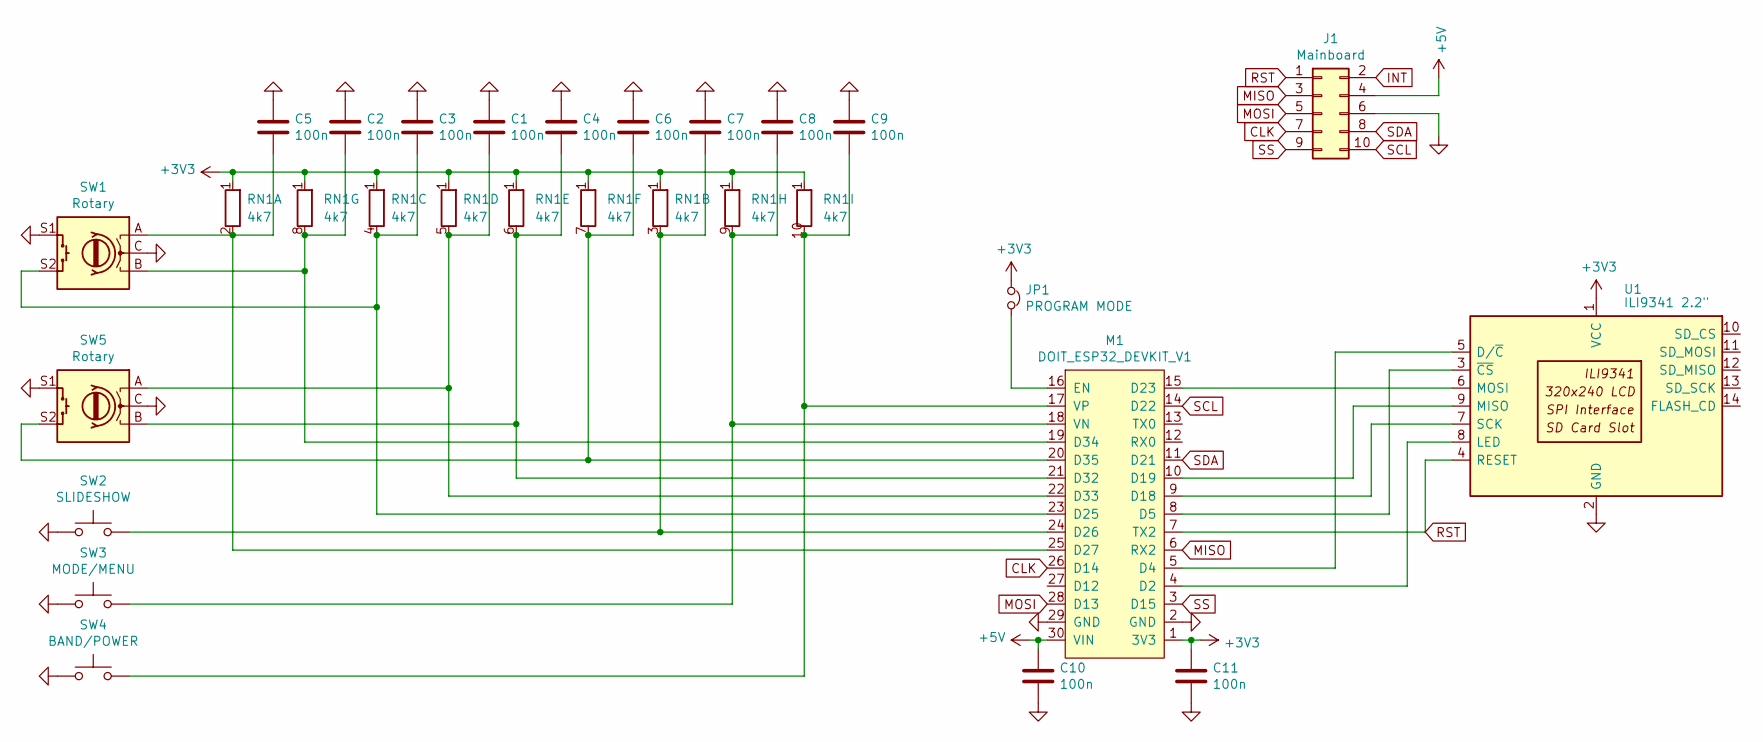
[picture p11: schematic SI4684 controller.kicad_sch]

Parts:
C1, C2, C3, C4, C5, C6, C7, C8, C9, C10, C11: 100n; C_Disc_D3.0mm_W2.0mm_P2.50mm
J1: Mainboard; IDC-Header_2x05_P2.54mm_Vertical
JP1: PROGRAM MODE; TestPoint_2Pads_Pitch2.54mm_Drill0.8mm
M1: DOIT_ESP32_DEVKIT_V1; ESP32_DOIT_DEVKIT_V1
RN1: 4k7; R_Array_SIP10
SW1, SW5: Rotary; RotaryEncoder_Alps_EC11E-Switch_Vertical_H20mm
SW2: SLIDESHOW; SW_PUSH_6mm_H7.3mm
SW3: MODE/MENU; SW_PUSH_6mm_H7.3mm
SW4: BAND/POWER; SW_PUSH_6mm_H7.3mm
U1: ILI9341 2.2"; CR2013-MI2120

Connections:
+3V3: C11.1, JP1.1, M1.1 (3V3), RN1.1 (R1), U1.1 (VCC)
+5V: C10.1, J1.4, M1.30 (VIN)
CLK: J1.7, M1.26 (D14)
GND: C1.1, C2.1, C3.1, C4.1, C5.1, C6.1, C7.1, C8.1, C9.1, C10.2, C11.2, J1.6, M1.2 (GND), M1.29 (GND), SW1.C, SW1.S1, SW2.1, SW3.1, SW4.1, SW5.C, SW5.S1, U1.2 (GND)
INT: J1.2
MISO: J1.3, M1.6 (RX2)
MOSI: J1.5, M1.28 (D13)
unnamed: M1.4 (D2), U1.8 (LED)
unnamed: M1.5 (D4), U1.5 (D/~C)
unnamed: M1.8 (D5), U1.3 (~CS)
unnamed: M1.9 (D18), U1.7 (SCK)
unnamed: M1.10 (D19), U1.9 (MISO)
unnamed: M1.15 (D23), U1.6 (MOSI)
unnamed: C3.2, M1.23 (D25), RN1.4 (R3.2), SW1.S2
unnamed: C7.2, M1.24 (D26), RN1.3 (R2.2), SW2.2
unnamed: C5.2, M1.25 (D27), RN1.2 (R1.2), SW1.A
unnamed: C4.2, M1.21 (D32), RN1.6 (R5.2), SW5.B
unnamed: C1.2, M1.22 (D33), RN1.5 (R4.2), SW5.A
unnamed: C2.2, M1.19 (D34), RN1.8 (R7.2), SW1.B
unnamed: C6.2, M1.20 (D35), RN1.7 (R6.2), SW5.S2
unnamed: JP1.2, M1.16 (EN)
unnamed: C8.2, M1.18 (VN), RN1.9 (R8.2), SW3.2
unnamed: C9.2, M1.17 (VP), RN1.10 (R9.2), SW4.2
RST: J1.1, M1.7 (TX2), U1.4 (RESET)
SCL: J1.10, M1.14 (D22)
SDA: J1.8, M1.11 (D21)
SS: J1.9, M1.3 (D15)

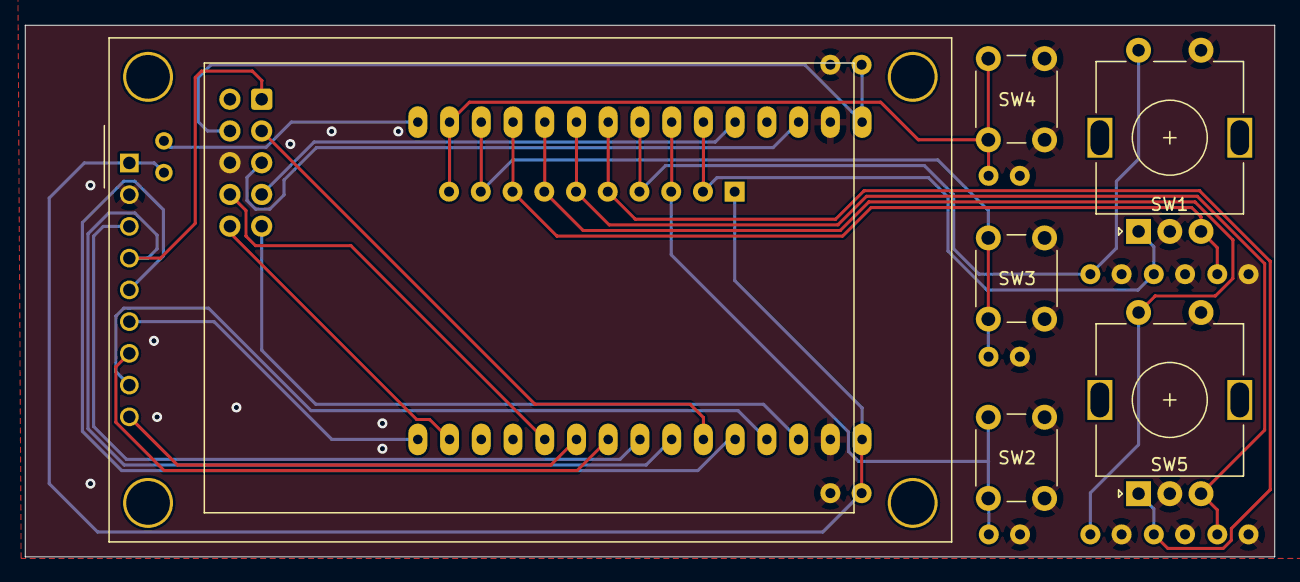
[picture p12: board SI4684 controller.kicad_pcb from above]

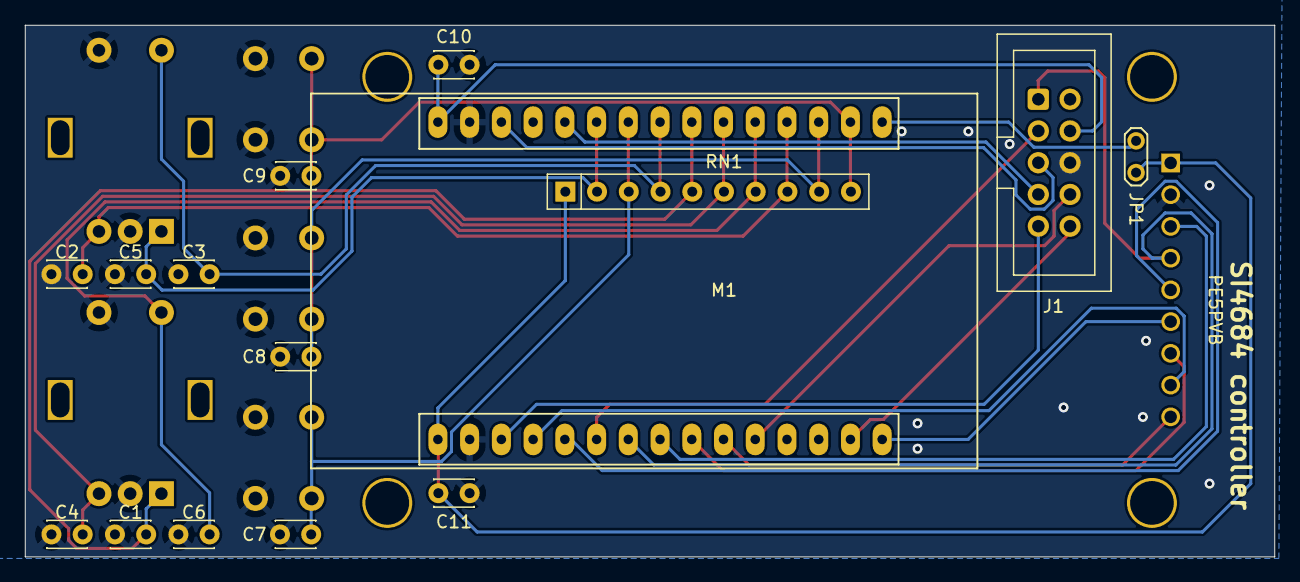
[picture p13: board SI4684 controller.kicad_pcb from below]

Board: 2 copper layers, 100.0 x 42.5 mm, 21 parts (15 on the bottom side), 26 nets.

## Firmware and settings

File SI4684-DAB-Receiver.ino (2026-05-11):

// SI4684 DAB Receiver - main Arduino sketch.
//
// Wires together every subsystem:
//   * SI4684 radio chip (SPI) - tuning, service data, MOT slideshow
//   * TFT_eSPI display (SPI) - all UI
//   * TPA6130A2 headphone amp (I2C) - audio output
//   * Dual rotary encoders + four buttons + IR remote - user input
//   * LittleFS - persistent slideshow cache
//   * EEPROM - settings and presets
//
// setup() initialises everything (in a specific order: brownout off, Serial,
// GPIO drive strength, LittleFS, EEPROM, headphone amp, TFT, radio).
// loop() is the cooperative scheduler: it calls IRReceiver(), ProcessDAB(),
// Communication(), then handles timers and polls all buttons/encoders.

#include <FS.h>
#include <LittleFS.h>
#include <TFT_eSPI.h>
#include <TimeLib.h>
#include "soc/soc.h"
#include "soc/rtc_cntl_reg.h"
#include <EEPROM.h>
#include <Wire.h>
#include "src/font.h"
#include "src/constants.h"
#include "src/graphics.h"
#include "src/language.h"
#include "src/gui.h"
#include "src/comms.h"
#include "src/slideshow.h"
#include "src/si4684.h"
#include "src/TPA6130A2.h"
#include "src/IRReceiver.h"

TPA6130A2 Headphones;
DAB radio;

TFT_eSPI tft = TFT_eSPI(240, 320);

bool autoslideshow;
bool ChannelListView;
bool direction;
bool displayreset;
bool memorystore;
bool menu;
bool menuopen;
bool resetFontOnNextCall;
bool seek;
bool setvolume;
bool ShowServiceInformation;
bool SlideShowAvailableOld;
bool SlideShowView;
bool store;
bool trysetservice;
bool tuned;
bool tuning;
byte audiomodeold;
byte ContrastSet;
byte CurrentTheme;
byte dabfreq;
byte dabfreqold;
byte displayflip;
byte eccold;
byte ficold;
byte language;
byte memorypos;
byte memoryposold;
byte memoryposstatus;
byte ptyold;
byte rotarymode;
byte servicetypeold;
byte subnetclient;
byte tot;
byte tunemode;
byte unit;
byte volume;
char _serviceName[17];
const uint8_t* currentFont = nullptr;
int ActiveColor;
int ActiveColorSmooth;
int BackgroundColor;
int BackgroundColor2;
int BackgroundColor3;
int BackgroundColor4;
int BarInsignificantColor;
int BarSignificantColor;
int Bitrateupdatetimer;
int GreyoutColor;
int InsignificantColor;
int InsignificantColorSmooth;
int menuoption = ITEM1;
int PrimaryColor;
int PrimaryColorSmooth;
volatile int rotary;
volatile int rotary2;
int rssi;
int rssiold = 200;
int RTlengthold;
int RTWidth;
int SecondaryColor;
int SecondaryColorSmooth;
int SignalLevelold;
int SignificantColor;
int SignificantColorSmooth;
int SNRupdatetimer;
int xPos;
int16_t SAvg;
int16_t SAvg2;
int16_t SignalLevel;
int8_t CNR;
int8_t CNRold;
String clockstringOld;
String datestringOld;
String EIDold;
String EnsembleNameOld;
String dabfreqStringOld;
String ITUold;
String PLold;
String PSold;
String RTold;
String SIDold;
String SignalLeveloldString;
uint16_t BitrateOld;
uint32_t _serviceID;
uint8_t freq = 0;
uint8_t service = 0;
unsigned long tottimer;
unsigned long rssiTimer;
unsigned long rtticker;
unsigned long rttickerhold;
unsigned long TuningTimer;
unsigned long VolumeTimer;

static const int8_t enc_states[]  = {0, -1, 1, 0, 1, 0, 0, -1, -1, 0, 0, 1, 0, 1, -1, 0};

typedef struct _Memory {
  byte      Channel;
  uint32_t  ServiceID;
  char      Label[17];
} DABMemory;

TFT_eSprite FullLineSprite = TFT_eSprite(&tft);
TFT_eSprite OneBigLineSprite = TFT_eSprite(&tft);
TFT_eSprite LongSprite = TFT_eSprite(&tft);
TFT_eSprite MediumSprite = TFT_eSprite(&tft);
TFT_eSprite ModeSprite = TFT_eSprite(&tft);
TFT_eSprite ShortSprite = TFT_eSprite(&tft);

DABMemory memory[EE_PRESETS_CNT];

// Forward declarations
void DefaultSettings(void);
void read_encoder(void);
void read_encoder2(void);
void DoMemoryPosTune(void);
void ProcessDAB(void);
void Seek(bool mode);
void deepSleep(void);
void StoreFrequency(void);
void closeVolume(void);
void KeyUp(void);
void KeyDown(void);
void KeyUp2(void);
void KeyDown2(void);
void ModeButtonPress(void);
void SlideShowButtonPress(void);
void StandbyButtonPress(void);
void ButtonPress(void);
void Button2Press(void);
void doRecovery(void);
void doStandby(void);
void DABSelectService(bool dir);
bool IsStationEmpty(void);

// One-time migration cleanup: older firmware buffered slideshow segments
// to /seg_N.bin files on LittleFS. The current code keeps them in RAM,
// so any leftover seg_*.bin from a previous firmware would just waste flash
// space. Wipe up to 96 of them at boot.
void cleanupSegmentFiles(void) {
  File root = LittleFS.open("/");
  if (!root || !root.isDirectory()) return;
  String victims[96];
  size_t n = 0;
  for (File f = root.openNextFile(); f && n < 96; f = root.openNextFile()) {
    if (f.isDirectory()) continue;
    String name = f.name();
    String path = name.startsWith("/") ? name : ("/" + name);
    if (path.startsWith("/seg_") && path.endsWith(".bin")) {
      victims[n++] = path;
    }
  }
  for (size_t i = 0; i < n; i++) LittleFS.remove(victims[i]);
}

// Edge-detect helper for buttons that have a single, immediate action.
// Returns true exactly once per physical press; rearmed only after the
// button is released. This keeps the main loop responsive (no blocking
// "wait for release" loops) while still firing the action just once.
static bool buttonEdge(uint8_t pin, bool& armed) {
  bool pressed = (digitalRead(pin) == LOW);
  if (!pressed) { armed = true; return false; }
  if (!armed) return false;
  armed = false;
  return true;
}

// One-shot initialisation called by the Arduino framework after boot.
// Order matters: brownout off → Serial → GPIO drive → filesystem → EEPROM →
// audio → display → radio → menu state → encoders/IR.
void setup(void) {
  // Disable brownout detector: occasional brief dips during SPI bursts otherwise
  // trigger a watchdog reset on this board.
  WRITE_PERI_REG(RTC_CNTL_BROWN_OUT_REG, 0);

  Serial.begin(1000000);
  delay(200);  // give USB-serial host time to re-attach after boot reset

  // Reduce drive strength on GPIOs sharing PCB tracks with the TFT/SPI
  // to lower EMI and crosstalk.
  gpio_set_drive_capability((gpio_num_t) 4, GPIO_DRIVE_CAP_0);
  gpio_set_drive_capability((gpio_num_t) 5, GPIO_DRIVE_CAP_0);
  gpio_set_drive_capability((gpio_num_t) 13, GPIO_DRIVE_CAP_0);
  gpio_set_drive_capability((gpio_num_t) 14, GPIO_DRIVE_CAP_0);
  gpio_set_drive_capability((gpio_num_t) 15, GPIO_DRIVE_CAP_0);
  gpio_set_drive_capability((gpio_num_t) 16, GPIO_DRIVE_CAP_0);
  gpio_set_drive_capability((gpio_num_t) 17, GPIO_DRIVE_CAP_0);
  gpio_set_drive_capability((gpio_num_t) 21, GPIO_DRIVE_CAP_0);
  gpio_set_drive_capability((gpio_num_t) 22, GPIO_DRIVE_CAP_0);

  // Initialize LittleFS; format only when mount fails (corrupt/uninitialized).
  // Setting `false` means "do not format on failure" so we can decide here.
  if (!LittleFS.begin(false)) {
    LittleFS.format();
    LittleFS.begin(false);
  }
  cleanupSegmentFiles();    // migration-only: remove leftover seg_*.bin from older firmware

  // EEPROM check byte acts as a schema version: when its value doesn't match
  // EE_CHECKBYTE_VALUE the previous layout is incompatible (or this is a fresh
  // device), so we wipe everything to defaults.
  EEPROM.begin(EE_TOTAL_CNT);
  if (EEPROM.readByte(EE_BYTE_CHECKBYTE) != EE_CHECKBYTE_VALUE) DefaultSettings();
  ContrastSet = EEPROM.readByte(EE_BYTE_CONTRASTSET);
  language = EEPROM.readByte(EE_BYTE_LANGUAGE);
  displayflip = EEPROM.readByte(EE_BYTE_DISPLAYFLIP);
  rotarymode = EEPROM.readByte(EE_BYTE_ROTARYMODE);
  tunemode = EEPROM.readByte(EE_BYTE_TUNEMODE);
  unit = EEPROM.readByte(EE_BYTE_UNIT);
  dabfreq = EEPROM.readByte(EE_BYTE_DABFREQ);
  volume = EEPROM.readByte(EE_BYTE_VOLUME);
  memorypos = EEPROM.readByte(EE_BYTE_MEMORYPOS);
  autoslideshow = EEPROM.readByte(EE_BYTE_AUTOSLIDESHOW);
  tot = EEPROM.readByte(EE_BYTE_TOT);
  CurrentTheme = EEPROM.readByte(EE_BYTE_THEME);
  radio.BufferSlideShow = EEPROM.readByte(EE_BYTE_BUFFERSLIDESHOW);

  for (int i = 0; i < EE_PRESETS_CNT; i++) {
    memory[i].Channel = EEPROM.readByte(i + EE_PRESETS_FREQ_START);
    EEPROM.get((i * 8) + EE_PRESETS_SERVICEID_START, memory[i].ServiceID);
    for (int y = 0; y < 16; y++) {
      memory[i].Label[y] = EEPROM.readByte((i * 17) + y + EE_PRESETS_NAME_START);
    }
    memory[i].Label[16] = '\0';
  }

  Headphones.Init();
  delay(50);
  Headphones.SetHiZ(0);
  delay(50);
  Headphones.SetVolume(volume);

  tft.init();
  tft.initDMA();
  doTheme();
  if (displayflip == 0) tft.setRotation(3); else tft.setRotation(1);

  pinMode(STANDBYBUTTON, INPUT);
  pinMode(MODEBUTTON, INPUT);
  pinMode(SLBUTTON, INPUT);
  pinMode(ROTARY_BUTTON, INPUT);
  pinMode(ROTARY_BUTTON2, INPUT);
  pinMode(ROTARY_PIN_A, INPUT);
  pinMode(ROTARY_PIN_B, INPUT);
  pinMode(ROTARY_PIN_2A, INPUT);
  pinMode(ROTARY_PIN_2B, INPUT);
  attachInterrupt(digitalPinToInterrupt(ROTARY_PIN_A), read_encoder, CHANGE);
  attachInterrupt(digitalPinToInterrupt(ROTARY_PIN_B), read_encoder, CHANGE);
  attachInterrupt(digitalPinToInterrupt(ROTARY_PIN_2A), read_encoder2, CHANGE);
  attachInterrupt(digitalPinToInterrupt(ROTARY_PIN_2B), read_encoder2, CHANGE);

  tft.setSwapBytes(true);
  tft.fillScreen(BackgroundColor);

  OneBigLineSprite.createSprite(270, 30);
  OneBigLineSprite.setSwapBytes(true);

  ShortSprite.createSprite(36, 16);
  ShortSprite.setSwapBytes(true);

  MediumSprite.createSprite(70, 16);
  MediumSprite.setSwapBytes(true);

  LongSprite.createSprite(150, 17);
  LongSprite.setSwapBytes(true);

  FullLineSprite.createSprite(308, 20);
  FullLineSprite.setSwapBytes(true);

  ModeSprite.createSprite(46, 47);
  ModeSprite.setTextDatum(TC_DATUM);
  ModeSprite.setSwapBytes(true);

  loadFonts(true);

  // Boot-time button shortcuts (held during power-on):
  //   SL only            → invert rotary direction (left/right) and save
  //   MODE only          → flip display orientation 180° and save
  //   SL + ROTARY        → reset all settings (DefaultSettings) and restart
  if (digitalRead(SLBUTTON) == LOW && digitalRead(ROTARY_BUTTON) == HIGH) {
    if (rotarymode == 0) rotarymode = 1; else rotarymode = 0;
    EEPROM.writeByte(EE_BYTE_ROTARYMODE, rotarymode);
    EEPROM.commit();

    analogWrite(CONTRASTPIN, ContrastSet * 2 + 27);
    tftPrint(0, myLanguage[language][1], 155, 70, ActiveColor, ActiveColorSmooth, 28);
    tftPrint(0, myLanguage[language][2], 155, 130, ActiveColor, ActiveColorSmooth, 28);
    while (digitalRead(SLBUTTON) == LOW);
  }

  if (digitalRead(MODEBUTTON) == LOW) {
    if (displayflip == 0) {
      displayflip = 1;
      tft.setRotation(1);
    } else {
      displayflip = 0;
      tft.setRotation(3);
    }
    EEPROM.writeByte(EE_BYTE_DISPLAYFLIP, displayflip);
    EEPROM.commit();

    analogWrite(CONTRASTPIN, ContrastSet * 2 + 27);
    tftPrint(0, myLanguage[language][3], 155, 70, ActiveColor, ActiveColorSmooth, 28);
    tftPrint(0, myLanguage[language][2], 155, 130, ActiveColor, ActiveColorSmooth, 28);
    while (digitalRead(MODEBUTTON) == LOW);
  }

  if (digitalRead(ROTARY_BUTTON) == LOW && digitalRead(SLBUTTON) == LOW) {
    DefaultSettings();

    analogWrite(CONTRASTPIN, ContrastSet * 2 + 27);
    tftPrint(0, myLanguage[language][10], 155, 70, ActiveColor, ActiveColorSmooth, 28);
    tftPrint(0, myLanguage[language][2], 155, 130, ActiveColor, ActiveColorSmooth, 28);
    while (digitalRead(ROTARY_BUTTON) == LOW && digitalRead(SLBUTTON) == LOW);
    ESP.restart();
  }

  tft.pushImage (0, 0, 320, 240, SplashScreen);
  tftPrint(0, myLanguage[language][72], 155, 15, ActiveColor, ActiveColorSmooth, 28);

  tftPrint(0, String(myLanguage[language][9]) + " " + String(VERSION), 160, 190, TFT_WHITE, TFT_DARKGREY, 16);

  for (int x = 0; x <= ContrastSet; x++) {
    analogWrite(CONTRASTPIN, x * 2 + 27);
    delay(30);
  }

  if (radio.begin(15)) {
    tftPrint(0, String(radio.getChipID()) + " v" + String(radio.getFirmwareVersion()), 160, 210, TFT_WHITE, TFT_DARKGREY, 16);
  } else {
    tftPrint(0, myLanguage[language][77], 160, 210, TFT_WHITE, TFT_DARKGREY, 16);
    for (;;);
  }

  delay(1500);

  if (tunemode == TUNE_MEM && !IsStationEmpty()) {
    DoMemoryPosTune();
  } else {
    if (tunemode == TUNE_MEM) tunemode = TUNE_MAN;
    radio.setFreq(dabfreq);
    EEPROM.get(EE_UINT32_SERVICEID, _serviceID);
    for (int i = 0; i < 16; i++) {
      _serviceName[i] = EEPROM.readByte(i + EE_CHAR17_SERVICENAME);
    }
  }
  if (_serviceID != 0 ) trysetservice = true;

  BuildDisplay();
  tottimer = millis();
  IRReceiverBegin();
}

// Main cooperative scheduler. Three subsystems run every iteration:
//   IRReceiver()    poll IR remote
//   ProcessDAB()    pump radio.Update() + UI updates
//   Communication() serial control protocol
// Everything else is timer-gated or input-driven and must stay non-blocking.
void loop(void) {
  IRReceiver();
  ProcessDAB();
  Communication();
  displayreset = false;

  if (seek) Seek(direction);

  if (tot != 0) {
    unsigned long totprobe = tot * 60000;
    if (millis() - tottimer >= totprobe) deepSleep();
  }

  // 500 ms after the user stops scrolling, commit either a preset store
  // (StoreFrequency) or finalise the tune. We detach the encoder interrupts
  // around the EEPROM write so the long flash erase doesn't lose ticks.
  if (millis() - TuningTimer >= 500) {
    if (store) {
      detachInterrupt(digitalPinToInterrupt(ROTARY_PIN_A));
      detachInterrupt(digitalPinToInterrupt(ROTARY_PIN_B));
      StoreFrequency();
      store = false;
      attachInterrupt(digitalPinToInterrupt(ROTARY_PIN_A), read_encoder, CHANGE);
      attachInterrupt(digitalPinToInterrupt(ROTARY_PIN_B), read_encoder, CHANGE);
    } else if (tuning) {
      radio.setFreq(dabfreq);
      tuning = false;
      if (tunemode == TUNE_MEM) trysetservice = true;
    }
  }

  if (setvolume && millis() - VolumeTimer >= 3000) {
    closeVolume();
  }

  if (!menu) {
    if (rotary2 == -1) KeyUp2();
    if (rotary2 == 1) KeyDown2();
  }

  if (rotary == -1) KeyUp();
  if (rotary == 1) KeyDown();

  // Buttons: Mode and Standby are long-press capable (1 s) and self-check
  // their own pin every iteration. The three other buttons act on the press
  // edge only and use the buttonEdge() helper to one-shot the action.
  static bool slArmed = true, rotArmed = true, rot2Armed = true;
  ModeButtonPress();                                                            // self-checks pin (long-press)
  if (!menu && buttonEdge(SLBUTTON, slArmed)) SlideShowButtonPress();
  if (!menu) StandbyButtonPress();                                              // self-checks pin (long-press)
  if (buttonEdge(ROTARY_BUTTON, rotArmed)) ButtonPress();
  if (!menu && buttonEdge(ROTARY_BUTTON2, rot2Armed)) Button2Press();
}

// Pump the radio driver and refresh the on-screen indicators. Skipped while
// `tuning` is true so we don't fight an in-progress retune.
void ProcessDAB(void) {
  if (!tuning) {
    radio.Update();
    SignalLevel = radio.getRSSI();
  }

  // panic() reports if the chip got into a hung state; doRecovery() reboots it.
  if (radio.panic()) doRecovery();

  if (trysetservice && radio.signallock) {
    for (byte x = 0; x < radio.numberofservices; x++) {
      if (_serviceID == radio.service[x].ServiceID) {
        radio.setService(x);
        radio.ServiceStart = true;
        trysetservice = false;
        store = true;
      }
    }
  }

  if (!SlideShowView && !menu) {
    if (!ChannelListView) ShowSignalLevel();
    ShowRT();
    if (!ShowServiceInformation && !ChannelListView) {
      if (autoslideshow && radio.SlideShowAvailable && radio.SlideShowUpdate) {
        SlideShowButtonPress();
      } else {
        ShowBitrate();
        ShowEID();
        ShowSID();
        ShowPTY();
        ShowProtectionlevel();
        ShowPS();
        ShowEN();
        ShowAudioMode();
        ShowClock();
        ShowSlideShowIcon();
        ShowECC();
      }
    }
  } else {
    if (radio.SlideShowAvailable && radio.SlideShowUpdate && !menu) {
      ShowSlideShow();
      radio.SlideShowUpdate = false;
    }
  }
}

// Leave the volume overlay and redraw whichever view was visible underneath.
void closeVolume(void) {
  if (ChannelListView) {
    BuildChannelList();
  } else if (ShowServiceInformation) {
    ShowServiceInfo();
  } else if (SlideShowView) {
    SlideShowView = false;
    SlideShowButtonPress();
  } else {
    BuildDisplay();
  }
}

// Cold-restart the SI4684 when it stops responding. Retunes to the last
// channel and asks ProcessDAB to re-select the previous service.
void doRecovery(void) {
  radio.begin(15);
  radio.setFreq(dabfreq);
  trysetservice = true;
}

// Step through the ensemble's services, skipping anything that isn't a
// regular audio service (type 0x00/0x04/0x05). Wraps at both ends.
void DABSelectService(bool dir) {
  if (radio.numberofservices > 0) {
    bool hasValidService = false;
    for (int i = 0; i < radio.numberofservices; i++) {
      if (radio.service[i].ServiceType == 0x00 ||
          radio.service[i].ServiceType == 0x04 ||
          radio.service[i].ServiceType == 0x05) {
        hasValidService = true;
        break;
      }
    }

    if (!hasValidService) return;

    if (dir) {
      radio.ServiceIndex = (radio.ServiceIndex + 1) % radio.numberofservices;
    } else {
      radio.ServiceIndex = (radio.ServiceIndex == 0) ? (radio.numberofservices - 1) : (radio.ServiceIndex - 1);
    }

    while (radio.service[radio.ServiceIndex].ServiceType != 0x00 &&
           radio.service[radio.ServiceIndex].ServiceType != 0x04 &&
           radio.service[radio.ServiceIndex].ServiceType != 0x05) {
      if (dir) {
        radio.ServiceIndex = (radio.ServiceIndex + 1) % radio.numberofservices;
      } else {
        radio.ServiceIndex = (radio.ServiceIndex == 0) ? (radio.numberofservices - 1) : (radio.ServiceIndex - 1);
      }
    }

    radio.setService(radio.ServiceIndex);
    radio.ServiceStart = true;
    store = true;
  }
}

// Persist the currently playing channel + service so the next boot can
// restore it. Triggered 500 ms after the user stops scrolling (see loop()).
void StoreFrequency(void) {
  EEPROM.put(EE_UINT32_SERVICEID, radio.service[radio.ServiceIndex].ServiceID);
  EEPROM.put(EE_BYTE_DABFREQ, dabfreq);
  for (int i = 0; i < 16; i++) {
    EEPROM.writeByte(i + EE_CHAR17_SERVICENAME, radio.PStext[i]);
  }
  EEPROM.commit();
  _serviceID = radio.service[radio.ServiceIndex].ServiceID;
}

// Rotary 1 click: stores/recalls a memory preset when in TUNE_MEM, toggles
// the channel-list view otherwise, or routes to DoMenu() when the menu is open.
void ButtonPress(void) {
  tottimer = millis();
  if (!menu) {
    if (tunemode == TUNE_MEM) {
      if (!memorystore) {
        memorystore = true;
        if (!IsStationEmpty()) memoryposstatus = MEM_EXIST;
        else memoryposstatus = MEM_NORMAL;
        ShowMemoryPos();
        ShowTuneMode();
      } else {
        memorystore = false;
        EEPROM.writeByte(memorypos + EE_PRESETS_FREQ_START, dabfreq);
        EEPROM.put((memorypos * 8) + EE_PRESETS_SERVICEID_START, radio.service[radio.ServiceIndex].ServiceID);
        for (int x = 0; x < 16; x++) {
          char character = radio.service[radio.ServiceIndex].Label[x];
          EEPROM.writeByte((memorypos * 17) + x + EE_PRESETS_NAME_START, character);
          memory[memorypos].Label[x] = character;
        }
        EEPROM.writeByte((memorypos * 17) + 16 + EE_PRESETS_NAME_START, '\0');
        memory[memorypos].Label[16] = '\0';
        memory[memorypos].Channel = dabfreq;
        memory[memorypos].ServiceID = radio.service[radio.ServiceIndex].ServiceID;
        EEPROM.commit();

        ShowTuneMode();
        if (memoryposstatus == MEM_DARK || memoryposstatus == MEM_EXIST) {
          memoryposstatus = MEM_NORMAL;
          ShowMemoryPos();
        }
      }
    } else {
      if (ChannelListView || SlideShowView || ShowServiceInformation) {
        BuildDisplay();
      } else {
        ChannelListView = true;
        BuildChannelList();
      }
    }
  } else {
    DoMenu();
  }
}

// Rotary 2 click: open/close the volume overlay. While open, rotary 2 ticks
// adjust the actual volume; a 3-second idle auto-closes it (see loop()).
void Button2Press(void) {
  memorystore = false;
  memoryposstatus = MEM_NORMAL;
  tottimer = millis();
  if (setvolume) {
    closeVolume();
  } else {
    setvolume = true;
    ShowVolume();
  }
}

// SL button: enter the full-screen slideshow view if a slideshow is currently
// available; otherwise toggle back to the normal radio display.
// Also called from ProcessDAB() when autoslideshow is enabled and from KeyUp()
// to leave slideshow view via the rotary.
void SlideShowButtonPress(void) {
  setvolume = false;
  memorystore = false;
  memoryposstatus = MEM_NORMAL;
  if (!SlideShowView && radio.SlideShowAvailable) {
    tft.fillScreen(TFT_BLACK);
    radio.SlideShowUpdate = true;
    SlideShowView = true;
    ShowServiceInformation = false;
  } else {
    if (SlideShowView) BuildDisplay();
    SlideShowView = false;
  }
}
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

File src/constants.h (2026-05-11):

// Project-wide constants: hardware pin assignments, EEPROM layout,
// UI line-spacing offsets, and the user-facing tune-mode / memory-status enums.
//
// Pin numbers map to the ESP32 dev-board GPIOs used by the schematic.
// EEPROM layout defines BOTH the size (EE_TOTAL_CNT) and the offsets of each
// stored value; the EE_CHECKBYTE_VALUE doubles as a schema version so older
// layouts get re-initialised via DefaultSettings() on first boot.

#ifndef CONSTANTS_H
#define CONSTANTS_H

// ---------- Hardware pin assignments ----------
#define ROTARY_PIN_A    27
#define ROTARY_PIN_B    34
#define ROTARY_PIN_2A   33
#define ROTARY_PIN_2B   32
#define ROTARY_BUTTON   25
#define ROTARY_BUTTON2  35
#define STANDBYBUTTON   36
#define SLBUTTON        26
#define MODEBUTTON      39
#define CONTRASTPIN     2          // PWM pin driving the LCD backlight

// ---------- GUI vertical spacing (px) for menu/list items ----------
#define ITEM_GAP        20
#define ITEM1           3
#define ITEM2           23
#define ITEM3           43
#define ITEM4           63
#define ITEM5           83
#define ITEM6           103
#define ITEM7           123
#define ITEM8           143
#define ITEM9           163
#define ITEM10          183

// ---------- EEPROM layout ----------
#define EE_PRESETS_CNT              99   // number of memory presets supported
#define EE_PRESETS_FREQUENCY        255  // sentinel marking an empty preset slot
#define EE_CHECKBYTE_VALUE          2    // bump to invalidate prior EEPROM layouts (forces DefaultSettings)

#define EE_TOTAL_CNT                2614 // total bytes claimed via EEPROM.begin()
#define EE_BYTE_CHECKBYTE           0
#define EE_BYTE_LANGUAGE            1
#define EE_BYTE_CONTRASTSET         2
#define EE_BYTE_DISPLAYFLIP         3
#define EE_BYTE_ROTARYMODE          4
#define EE_BYTE_TUNEMODE            5
#define EE_BYTE_BUFFERSLIDESHOW     6
#define EE_BYTE_UNIT                7
#define EE_BYTE_DABFREQ             8
#define EE_BYTE_VOLUME              9
#define EE_BYTE_MEMORYPOS           10
#define EE_BYTE_THEME               11
#define EE_BYTE_AUTOSLIDESHOW       12
#define EE_BYTE_TOT                 13
#define EE_UINT32_SERVICEID         14   // 4 bytes: last-used service ID
#define EE_CHAR17_SERVICENAME       22   // 17 bytes: last-used service label (16 chars + NUL)
#define EE_PRESETS_FREQ_START       39   // 1 byte * EE_PRESETS_CNT: per-preset channel index
#define EE_PRESETS_SERVICEID_START  138  // 8 bytes * EE_PRESETS_CNT: per-preset 64-bit service ID
#define EE_PRESETS_NAME_START       930  // 17 bytes * EE_PRESETS_CNT: per-preset label

// ---------- UI strings + enums ----------
static const char* const unitString[] = {"dBμV", "dBf", "dBm"};
static const char* const Theme[] = {"Elegant", "GoldenDusk", "Vibrant", "Serenity", "Luminous", "Radiant", "Sunset"};

// Manual = rotary changes channel; Auto = seek; Mem = step through presets.
enum RADIO_TUNE_MODE {
  TUNE_MAN, TUNE_AUTO, TUNE_MEM
};

// Visual state of the memory-position indicator.
enum RADIO_MEM_POS_STATUS {
  MEM_DARK, MEM_NORMAL, MEM_EXIST
};

#endif

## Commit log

2024-03-11 Upload STL's
    [back.stl, bottom.stl, bus.stl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]
2024-03-11 Added schematics and gerbers
    [SI4684 controller-B_Cu.gbr, SI4684 controller-B_Mask.gbr, SI4684 controller-B_Paste.gbr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]
2024-03-13 Enabled DMA
2024-03-14 Mod on rotary encoder routine
2024-03-14 Rotary encoder mod reverted
    [SI4684-DAB-Receiver.ino]
2024-03-15 Update STL
2024-03-20 STL update
    [bus.stl]
2024-05-16 Fixed a problem where the radio could hang
    [SI4684-DAB-Receiver.ino]
2024-05-18 Fixed a bug with EID/SID conversion
    [si4684.cpp]
2024-07-13 Fixed a problem some muxes won't load
    [si4684.cpp]
2024-07-20 Added serial protocol + fix error closing MOT
    [SI4684-DAB-Receiver.ino, comms.cpp, si4684.cpp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]
2024-07-21 Fixed regression in JPG viewer
    [slideshow.cpp]
2024-07-31 Added slideshow buffering
    Auto slideshow fix.
    Bugfixes
    [SI4684-DAB-Receiver.ino, comms.cpp, constants.h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]
2025-01-22 fix time and date not updating
    [si4684.cpp]
2025-01-22 fix compilation on case sensitive systems
    [TPA6130A2.cpp]
2025-01-26 Added Kicad files
    [SI4684 controller.kicad_pcb, SI4684 controller.kicad_sch, SI4684.kicad_pcb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]
2026-02-22 Additional bugfixing on slideshow parser
    [si4684.cpp]

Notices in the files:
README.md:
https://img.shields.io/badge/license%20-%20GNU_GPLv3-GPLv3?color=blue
